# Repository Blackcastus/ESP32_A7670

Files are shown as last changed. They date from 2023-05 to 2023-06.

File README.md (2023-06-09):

Designer: Mr.Duc_Hien

## Lưu ý thiết kế Hardware.
- Khóa cửa thường hở 12V (dài x rộng x cao tối thiểu 49mm x 30mm x 20mm). -> check notOK
- Vị trí cổng USB trên tủ thay bằng khay sim. -> check OK
- Thêm led status cho simcom và PGS.
- Sử dụng các loại header cắp khác nhau để không bị cắm nhầm.
- Kiếm lại lò xo cho button.
- Thiết kế lại bus cắm LCD.
- Chú ý căn chỉnh LCD cho khớp với vỏ tủ.
- Kiếm lại IC UART - I2C chp bộ BMS.
- Thêm RS485 viết bằng software uart.

## Block diagram.
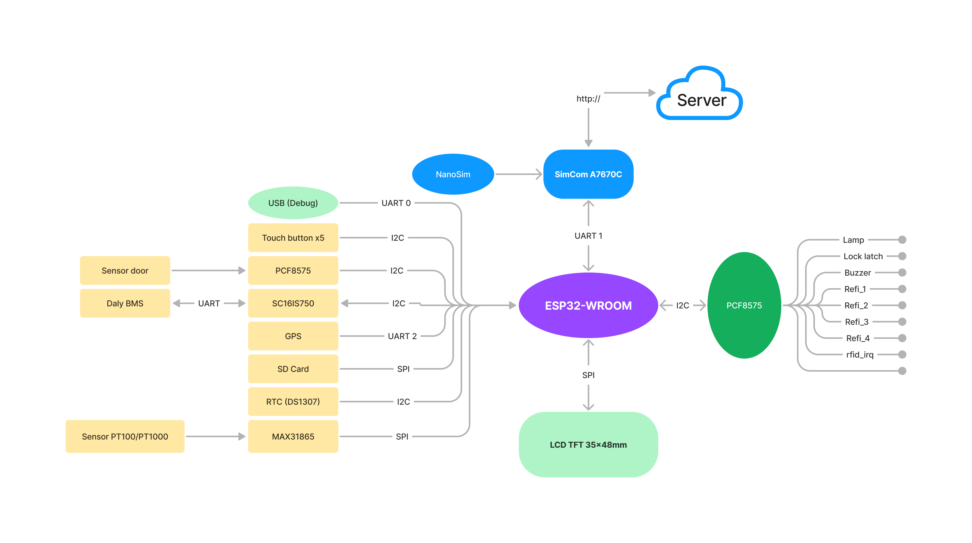
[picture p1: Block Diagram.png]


## Hardware MCU và Display

1. **Hardware board MCU.**

    **1.1. Thông số kỹ thuật board MCU:**

    * Nguồn input 12V được lấy từ bộ pin 12V hoặc qua adapter 12V.
    * MCU : ESP32-WROOM, debug qua USB.
    * Cảm biến: nhiệt độ PT100, cảm biến cửa.
    * Lấy vị trí GPS.
    * Kết nối module SIM 3G.
    * Đọc/lưu thời gian thực qua RTC.
    * Lưu dữ liệu vào thẻ nhớ.
    * Kết nối với màn hình LCD TFT 2Inch.
    * kết nối với bàn phím cảm ứng.
    * Có RS485 (sử dụng code software serial mới dùng được).
    * Điều khiển block lạnh.
    * Điều khiển khóa tủ.
    * Điều khiển đèn chiếu sáng trong tủ.
    * Điều khiểu chuông báo.
    * Đọc dữ liệu quản lý pin từ daly BMS.
    
    **1.2. Hình ảnh bộ quản lý pin BMS**

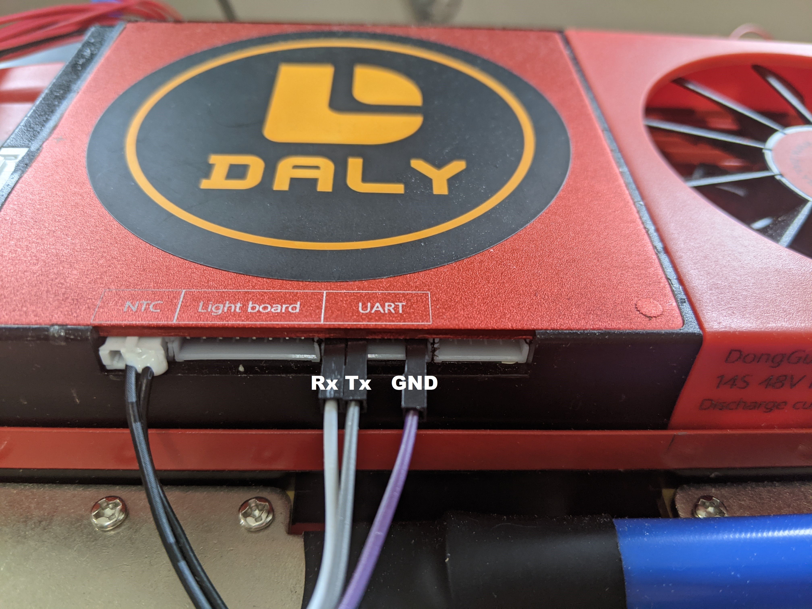
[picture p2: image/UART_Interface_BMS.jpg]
    

    **1.3. Hình ảnh board**

    Top layer

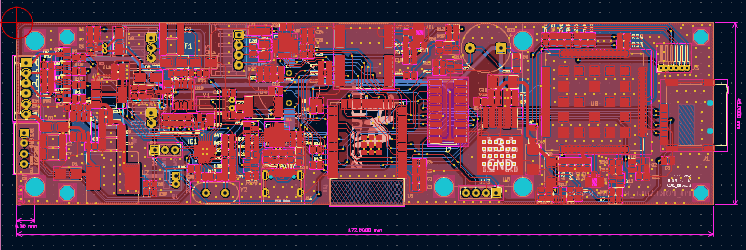
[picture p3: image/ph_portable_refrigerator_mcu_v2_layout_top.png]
    
    
    Bottom layer

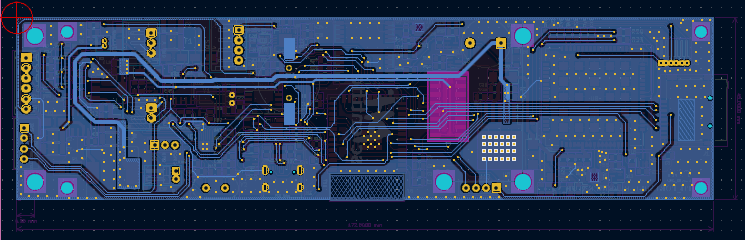
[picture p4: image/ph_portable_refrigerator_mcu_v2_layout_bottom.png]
    

    Top 3D

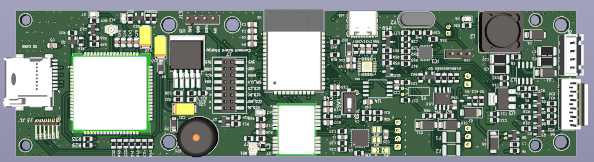
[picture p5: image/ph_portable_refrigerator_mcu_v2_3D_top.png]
    

    Bottom 3D

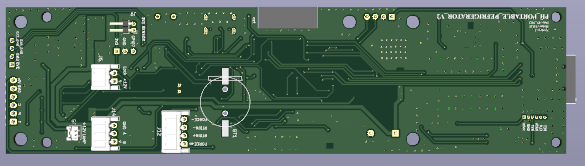
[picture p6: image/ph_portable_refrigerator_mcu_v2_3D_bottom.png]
    

2. Hardware board display.

    **2.1. Thông số kỹ thuật board display**
    * Điện áp: 3V3.
    * Giao tiếp với LCD qua giao thức SPI.
    * Giao tiếp với bàn phím cảm ứng qua giao thức I2C.
    * Có chuông báo.

    **2.2. Hình ảnh board**

    Top layer

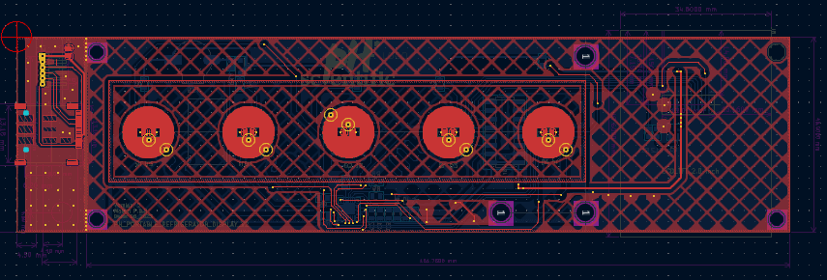
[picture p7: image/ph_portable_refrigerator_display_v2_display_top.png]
    
    
    Bottom layer
    
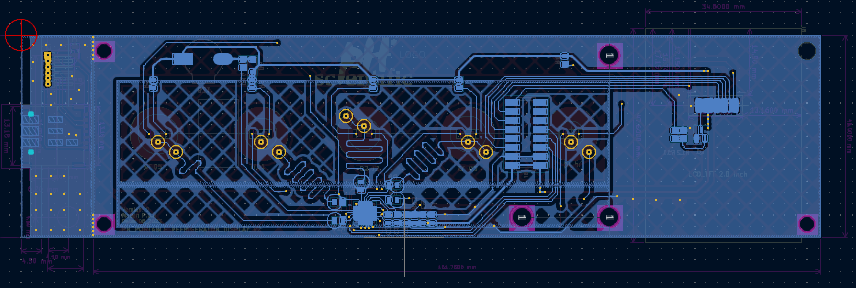
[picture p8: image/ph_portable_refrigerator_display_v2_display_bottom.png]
    

    Top 3D

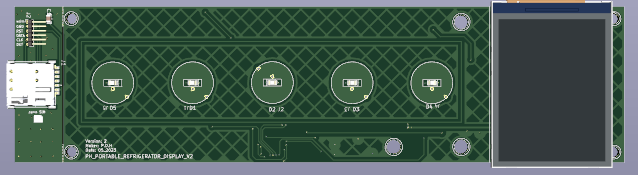
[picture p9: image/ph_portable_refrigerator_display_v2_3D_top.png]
    

    Bottom 3D

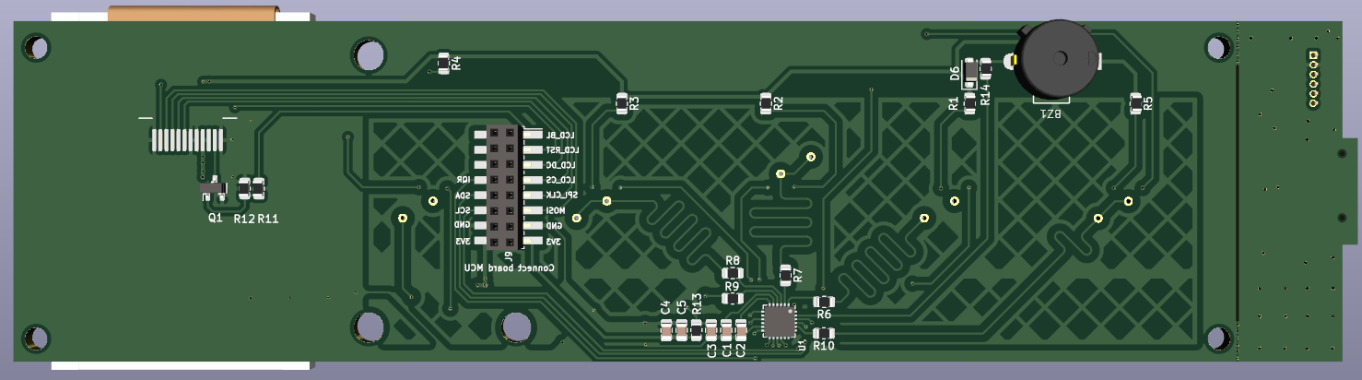
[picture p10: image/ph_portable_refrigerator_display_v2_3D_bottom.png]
    

    Board sau khi hàn 

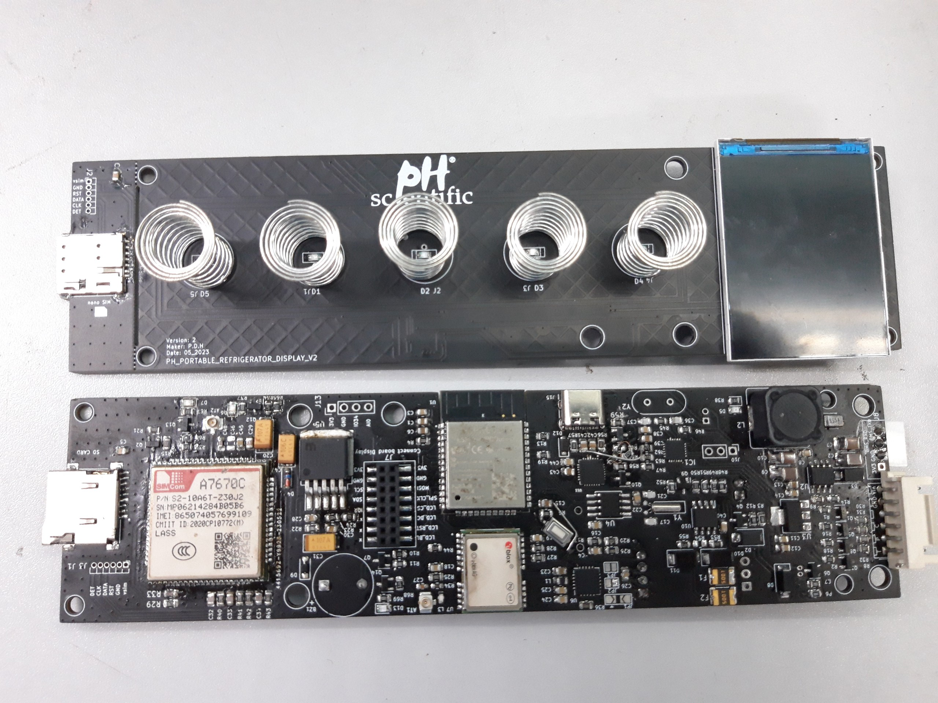
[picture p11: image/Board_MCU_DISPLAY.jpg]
    

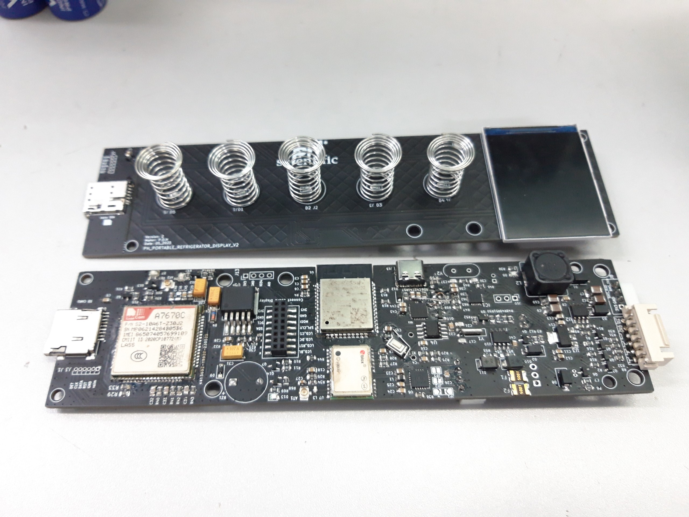
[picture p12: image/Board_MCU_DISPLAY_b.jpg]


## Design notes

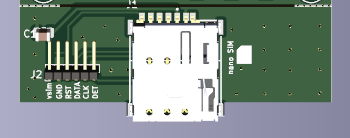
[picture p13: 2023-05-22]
Hardware/image/module_nanoSIM.png

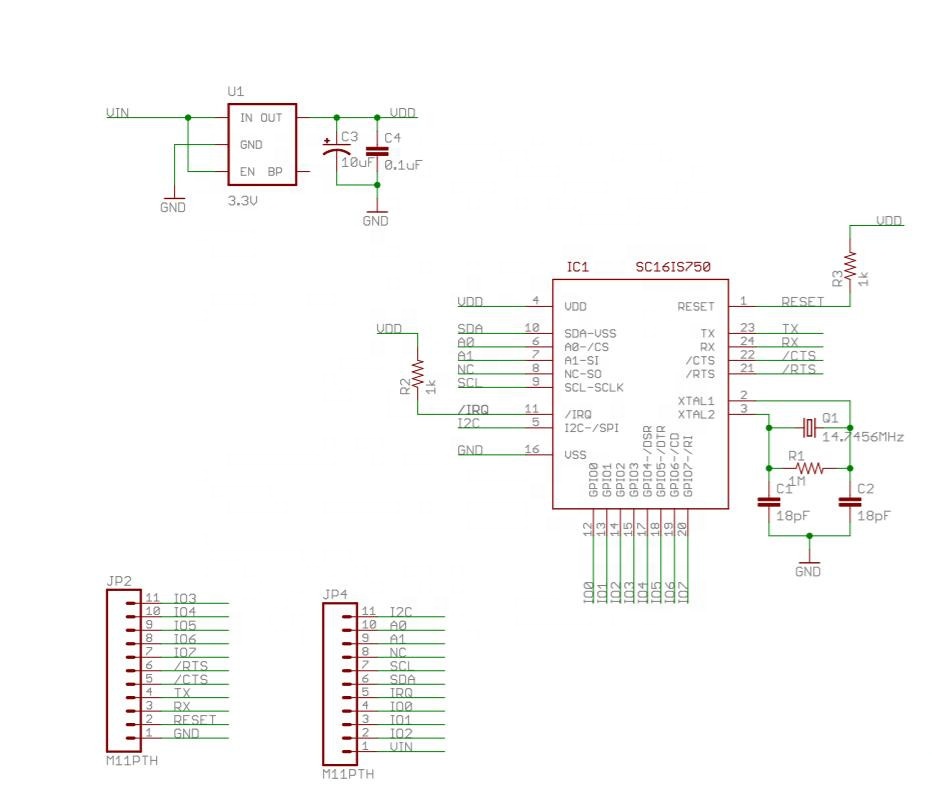
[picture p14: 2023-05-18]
Hardware/power_v2/Uart to I2C.jpeg

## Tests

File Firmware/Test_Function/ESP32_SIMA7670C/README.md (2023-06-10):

#ESP32 - SIMCOM A7670C

#Connect
    *Communication: UART.
    *Baut rate: 115200.

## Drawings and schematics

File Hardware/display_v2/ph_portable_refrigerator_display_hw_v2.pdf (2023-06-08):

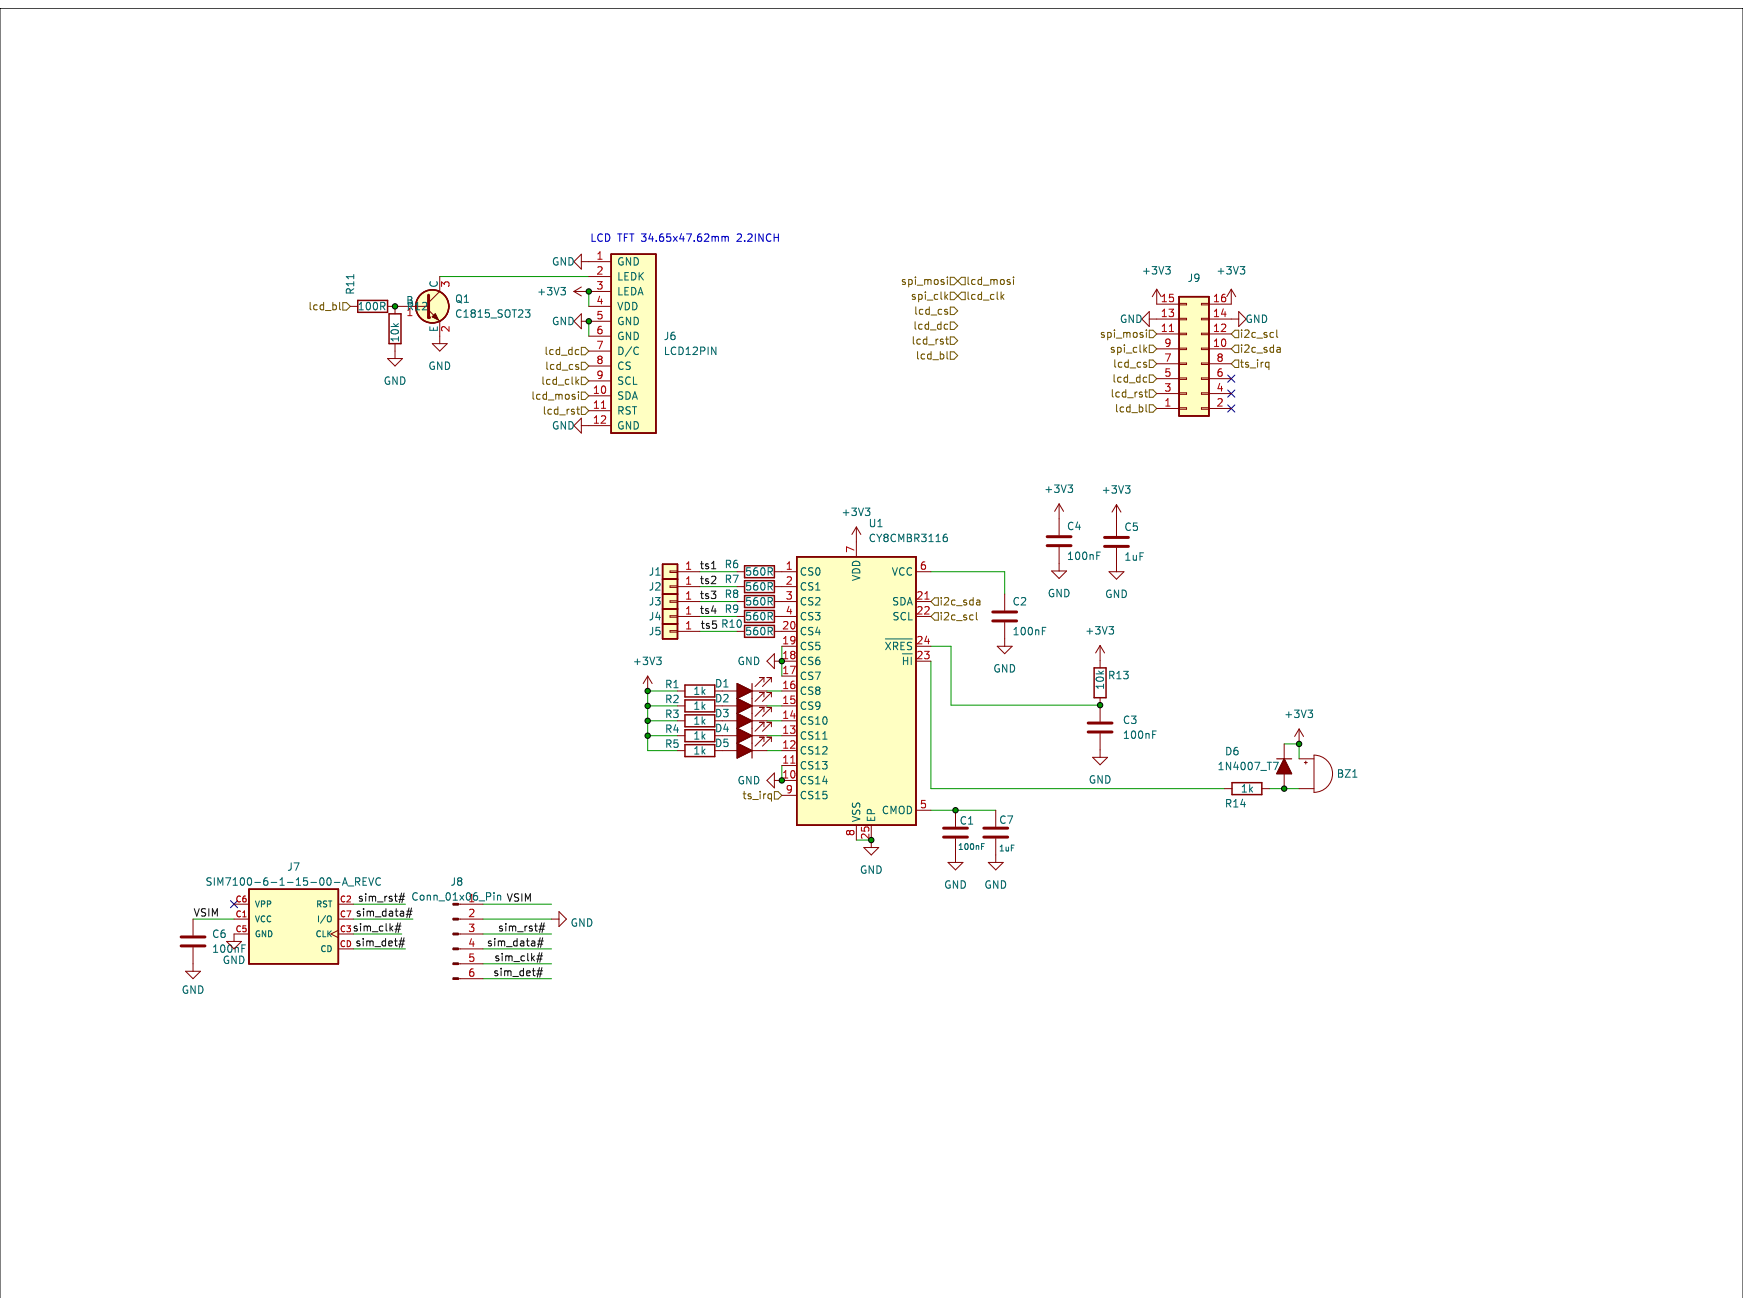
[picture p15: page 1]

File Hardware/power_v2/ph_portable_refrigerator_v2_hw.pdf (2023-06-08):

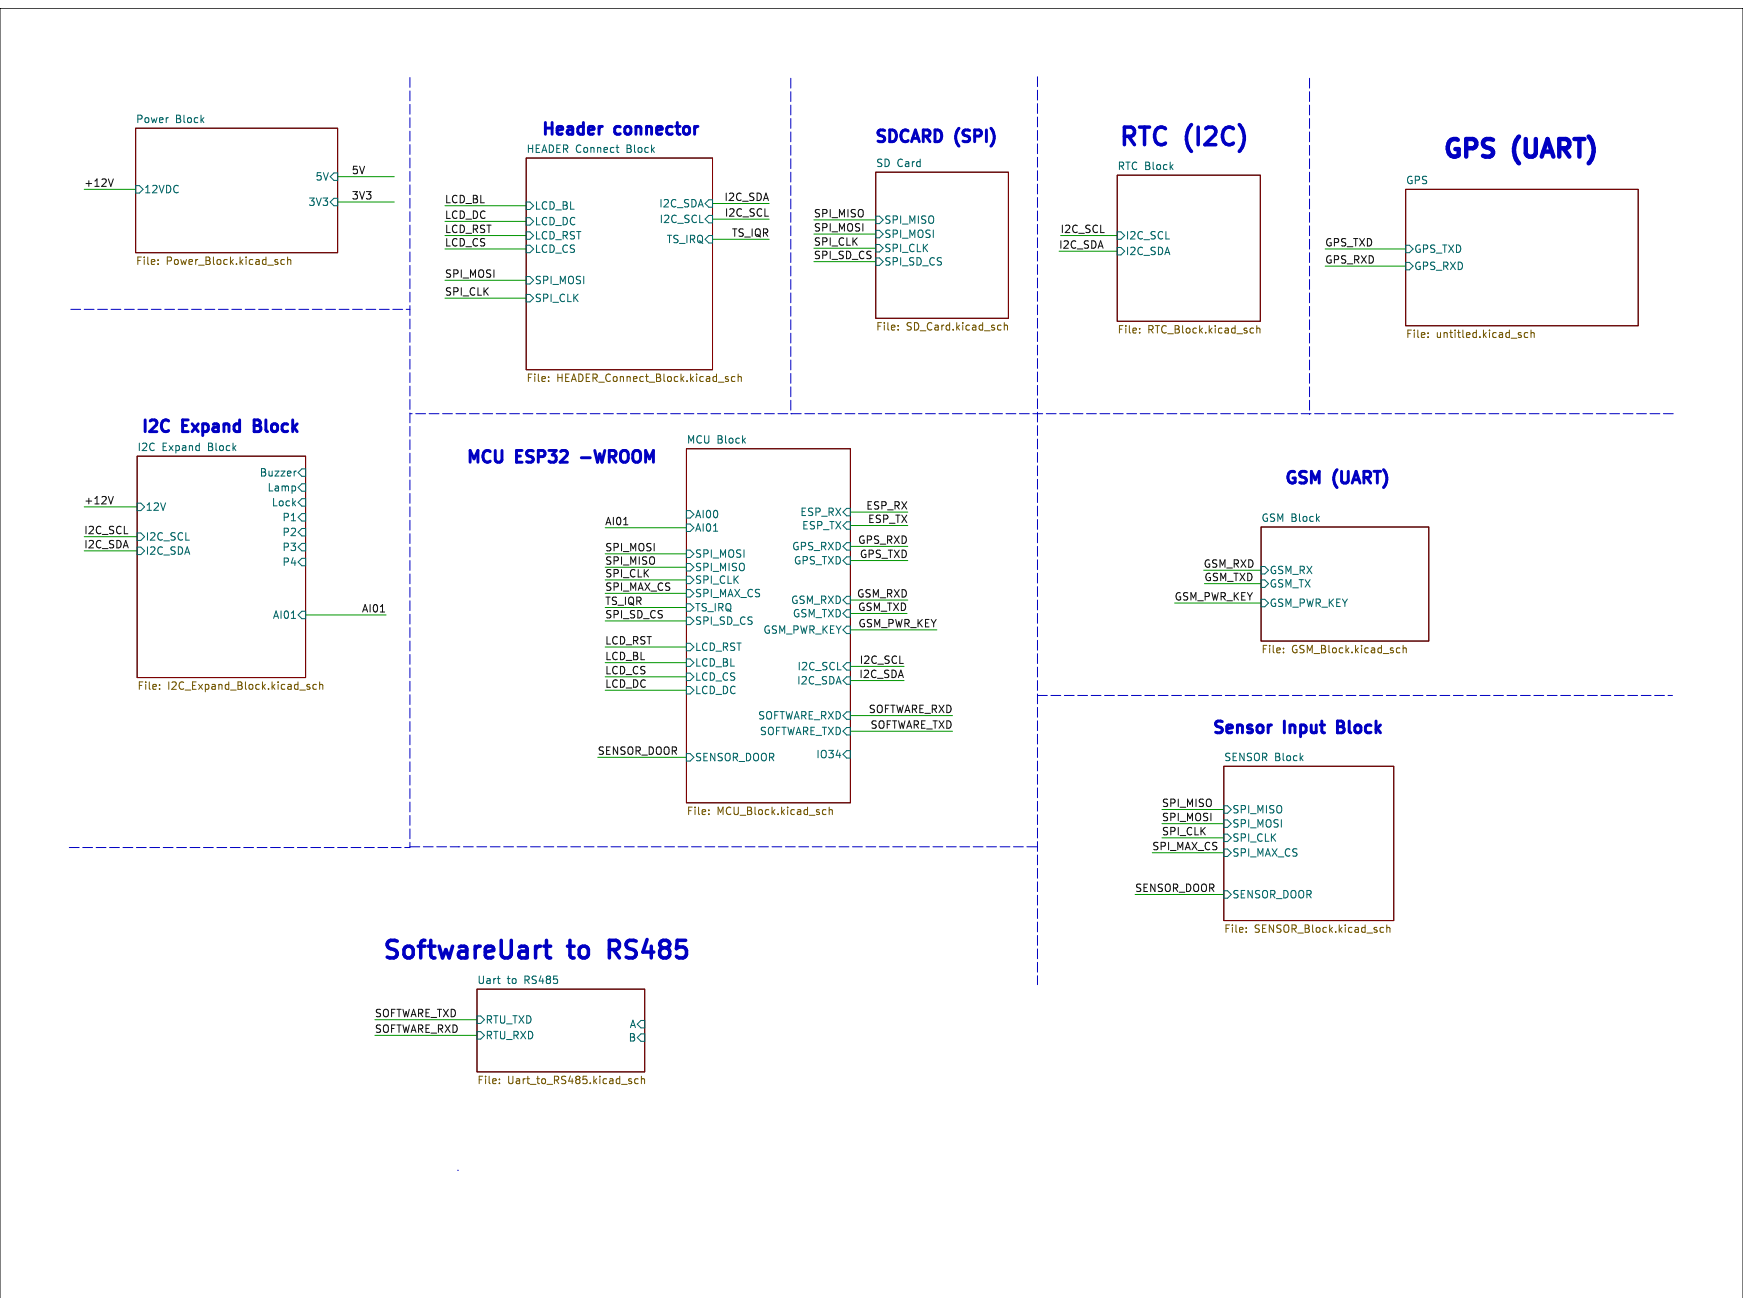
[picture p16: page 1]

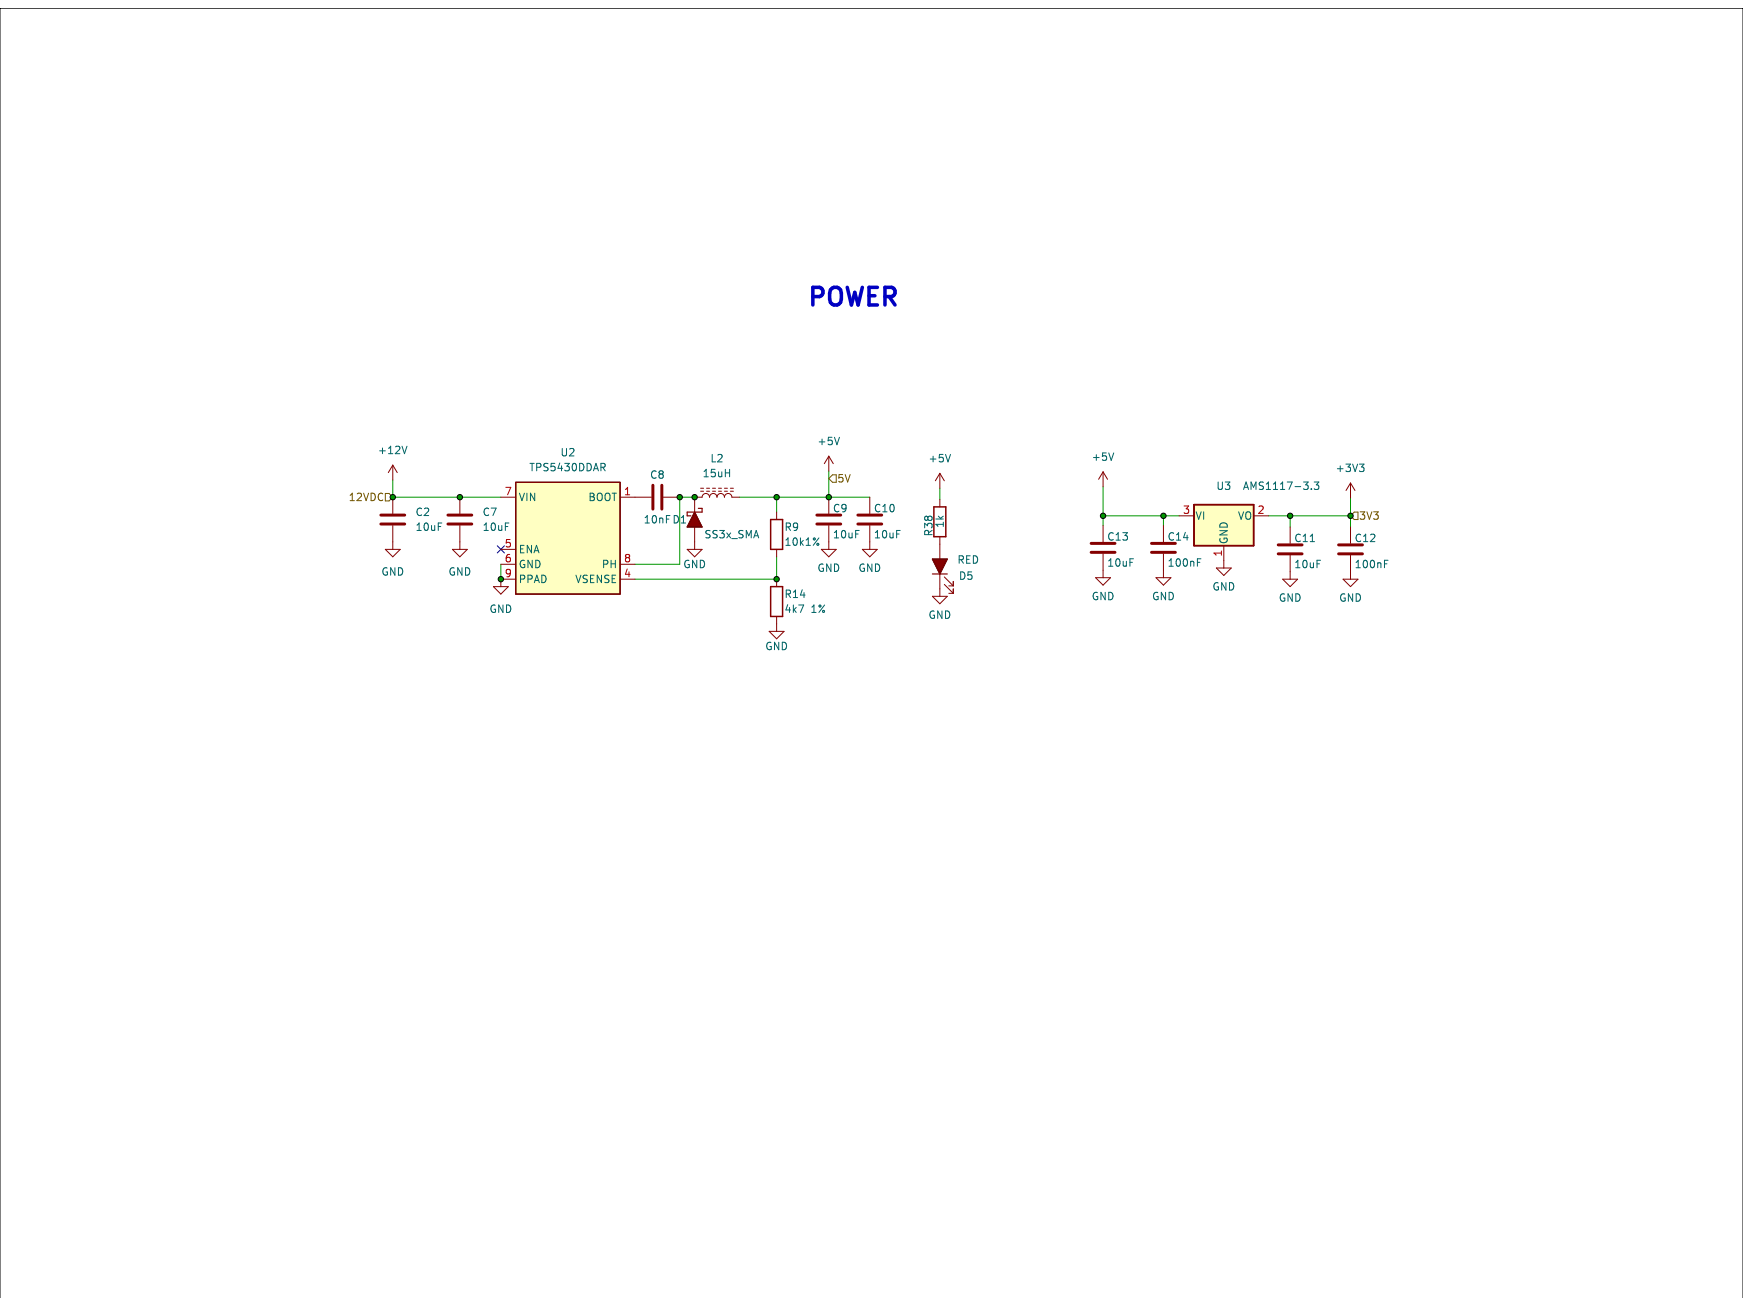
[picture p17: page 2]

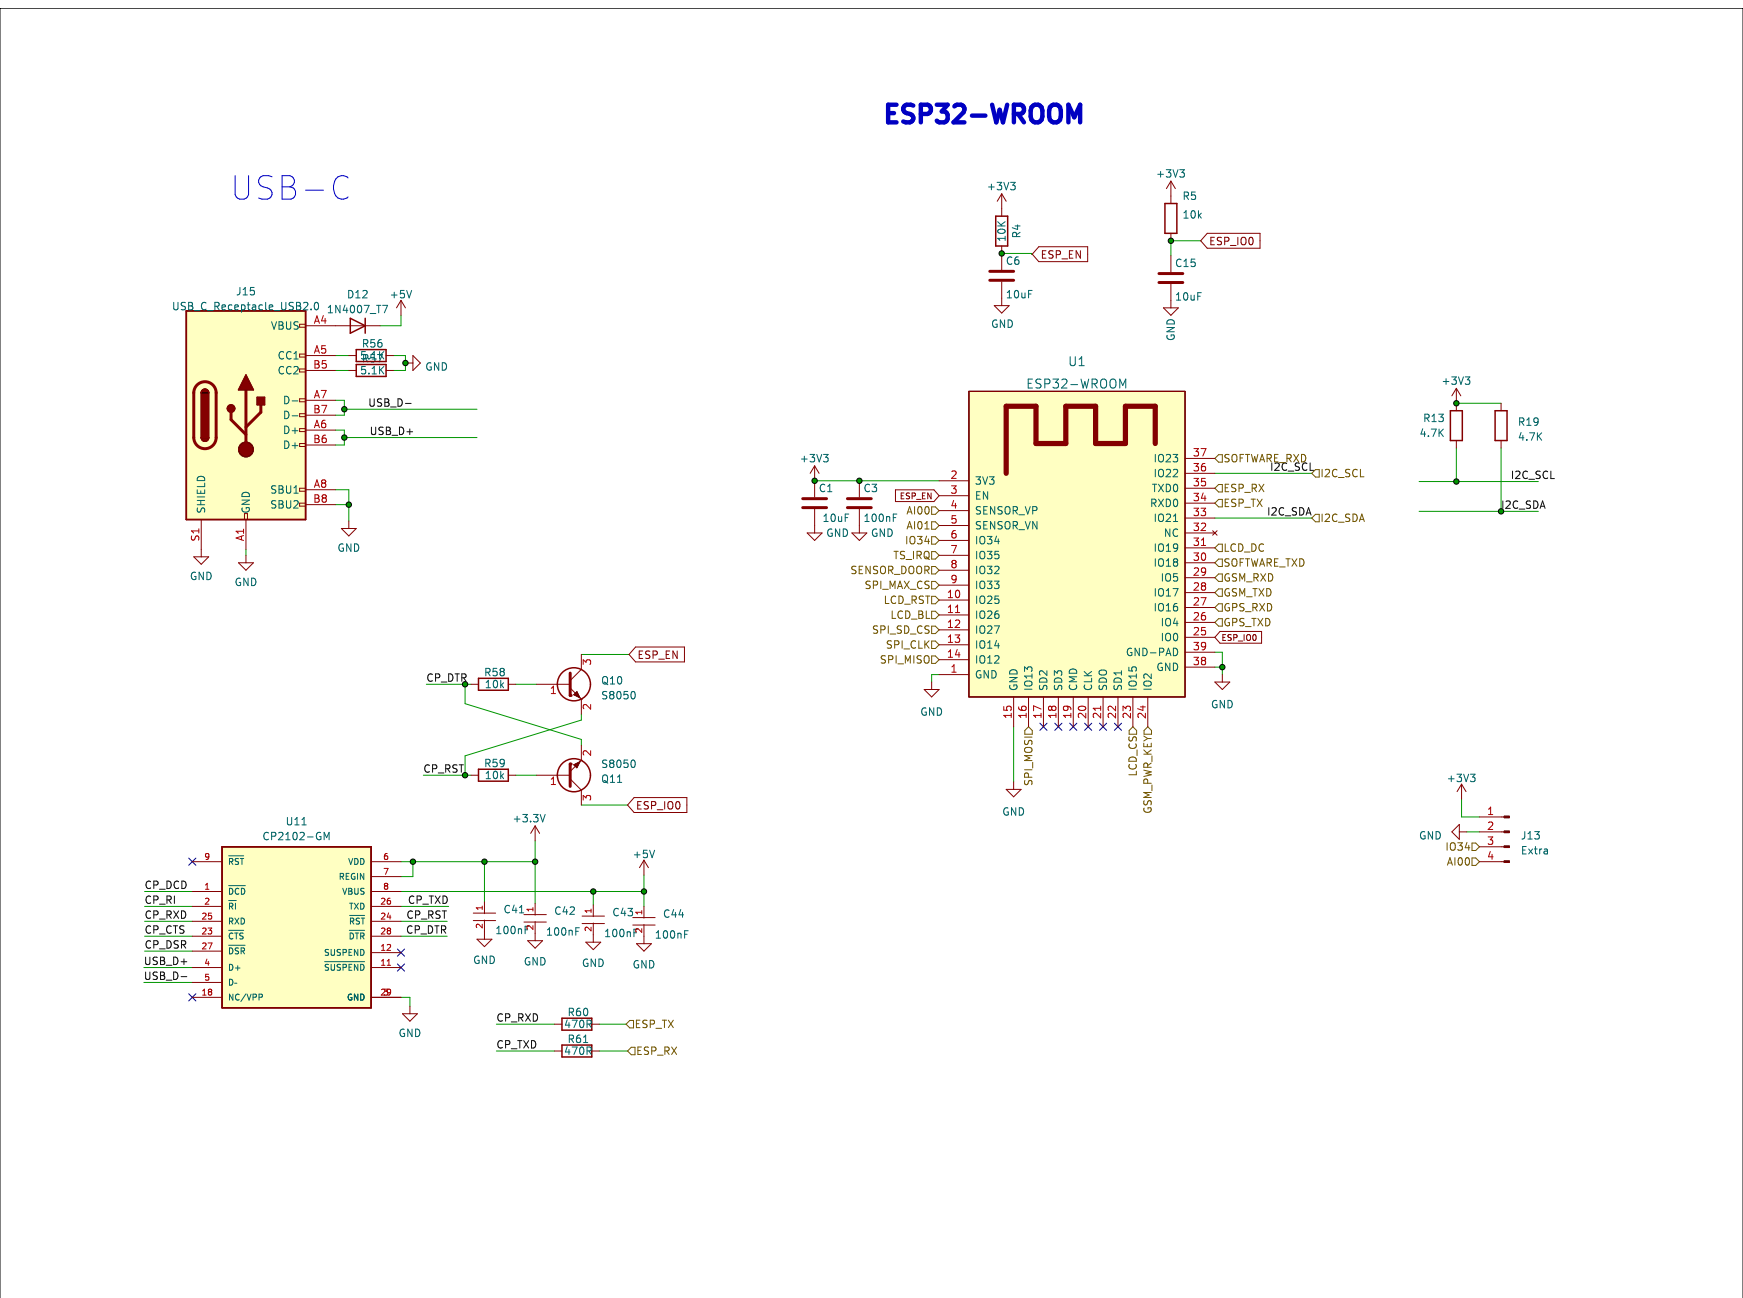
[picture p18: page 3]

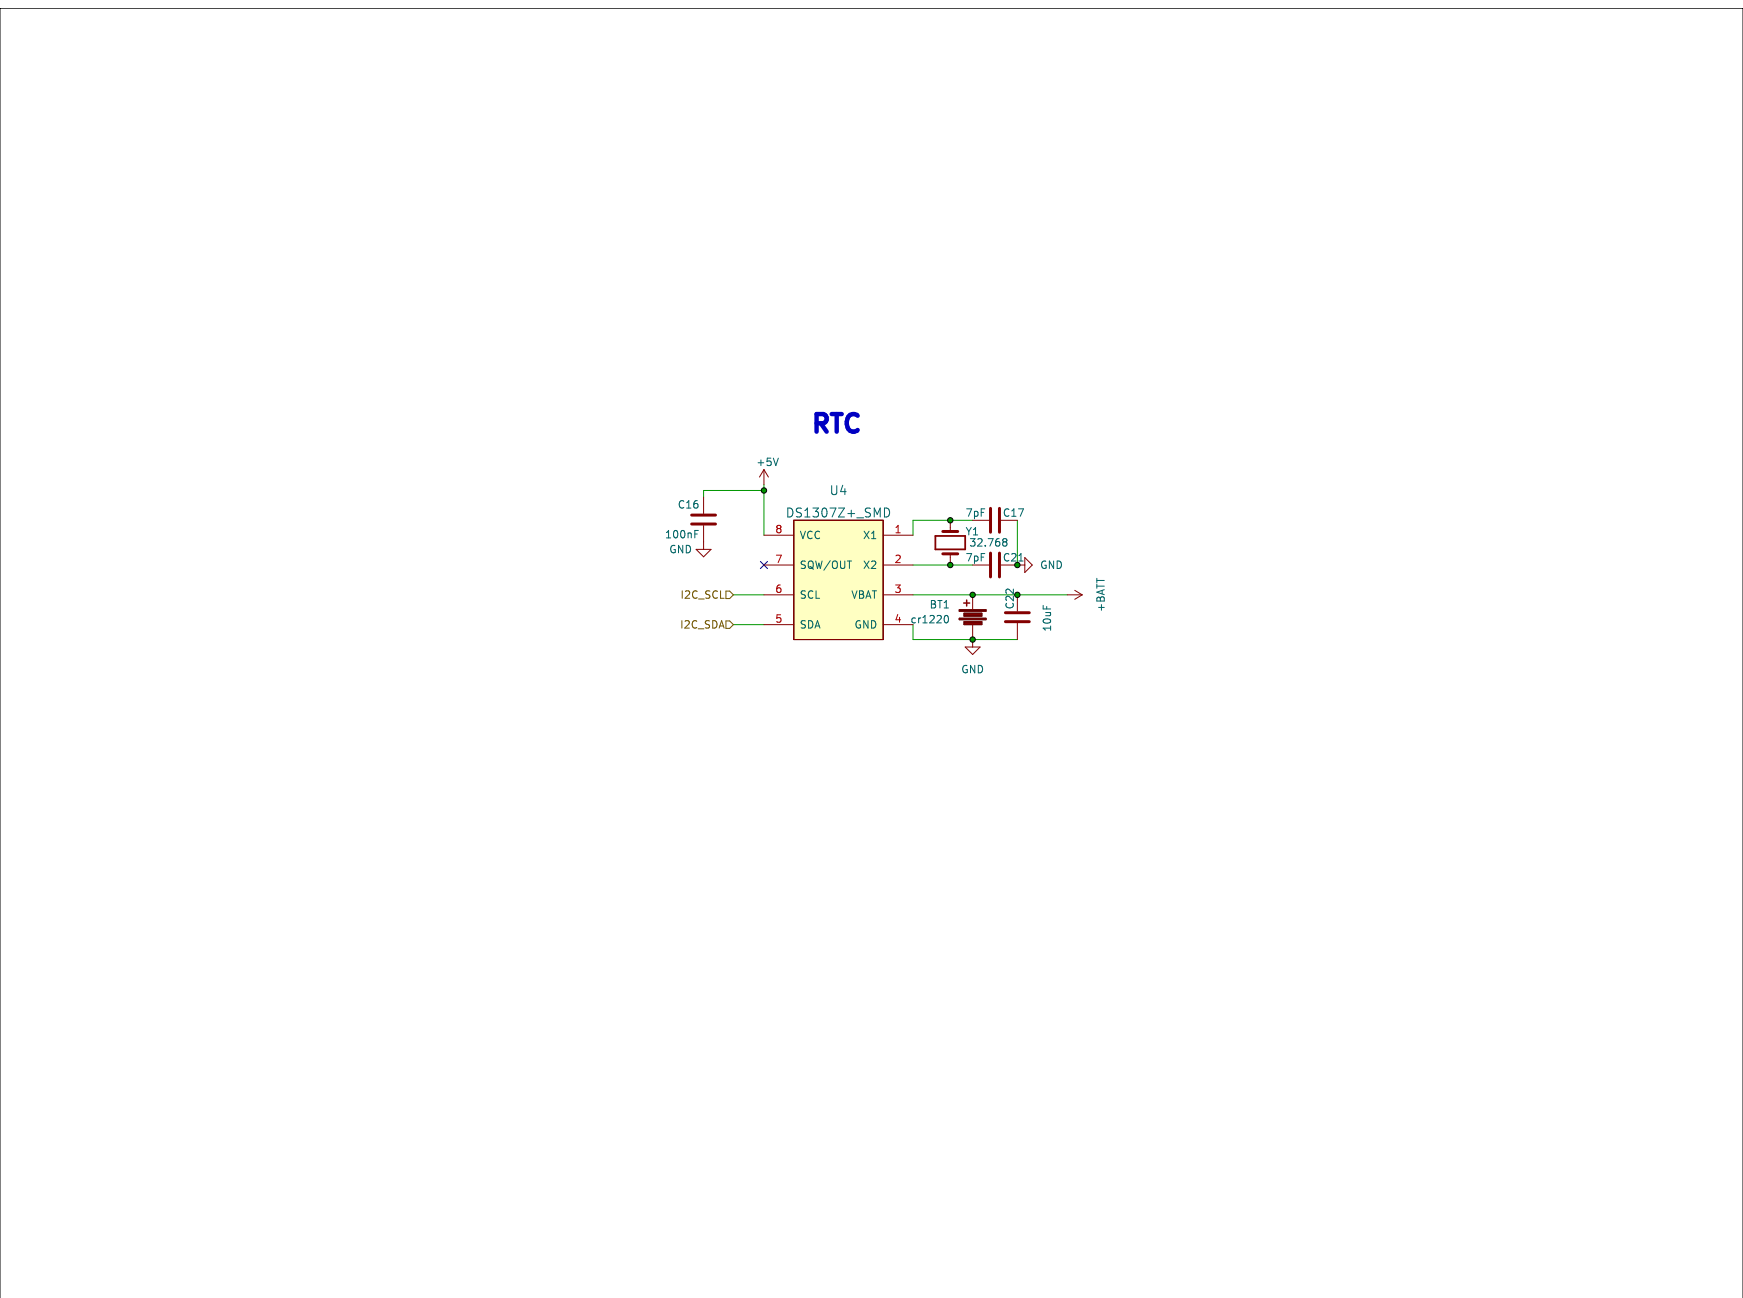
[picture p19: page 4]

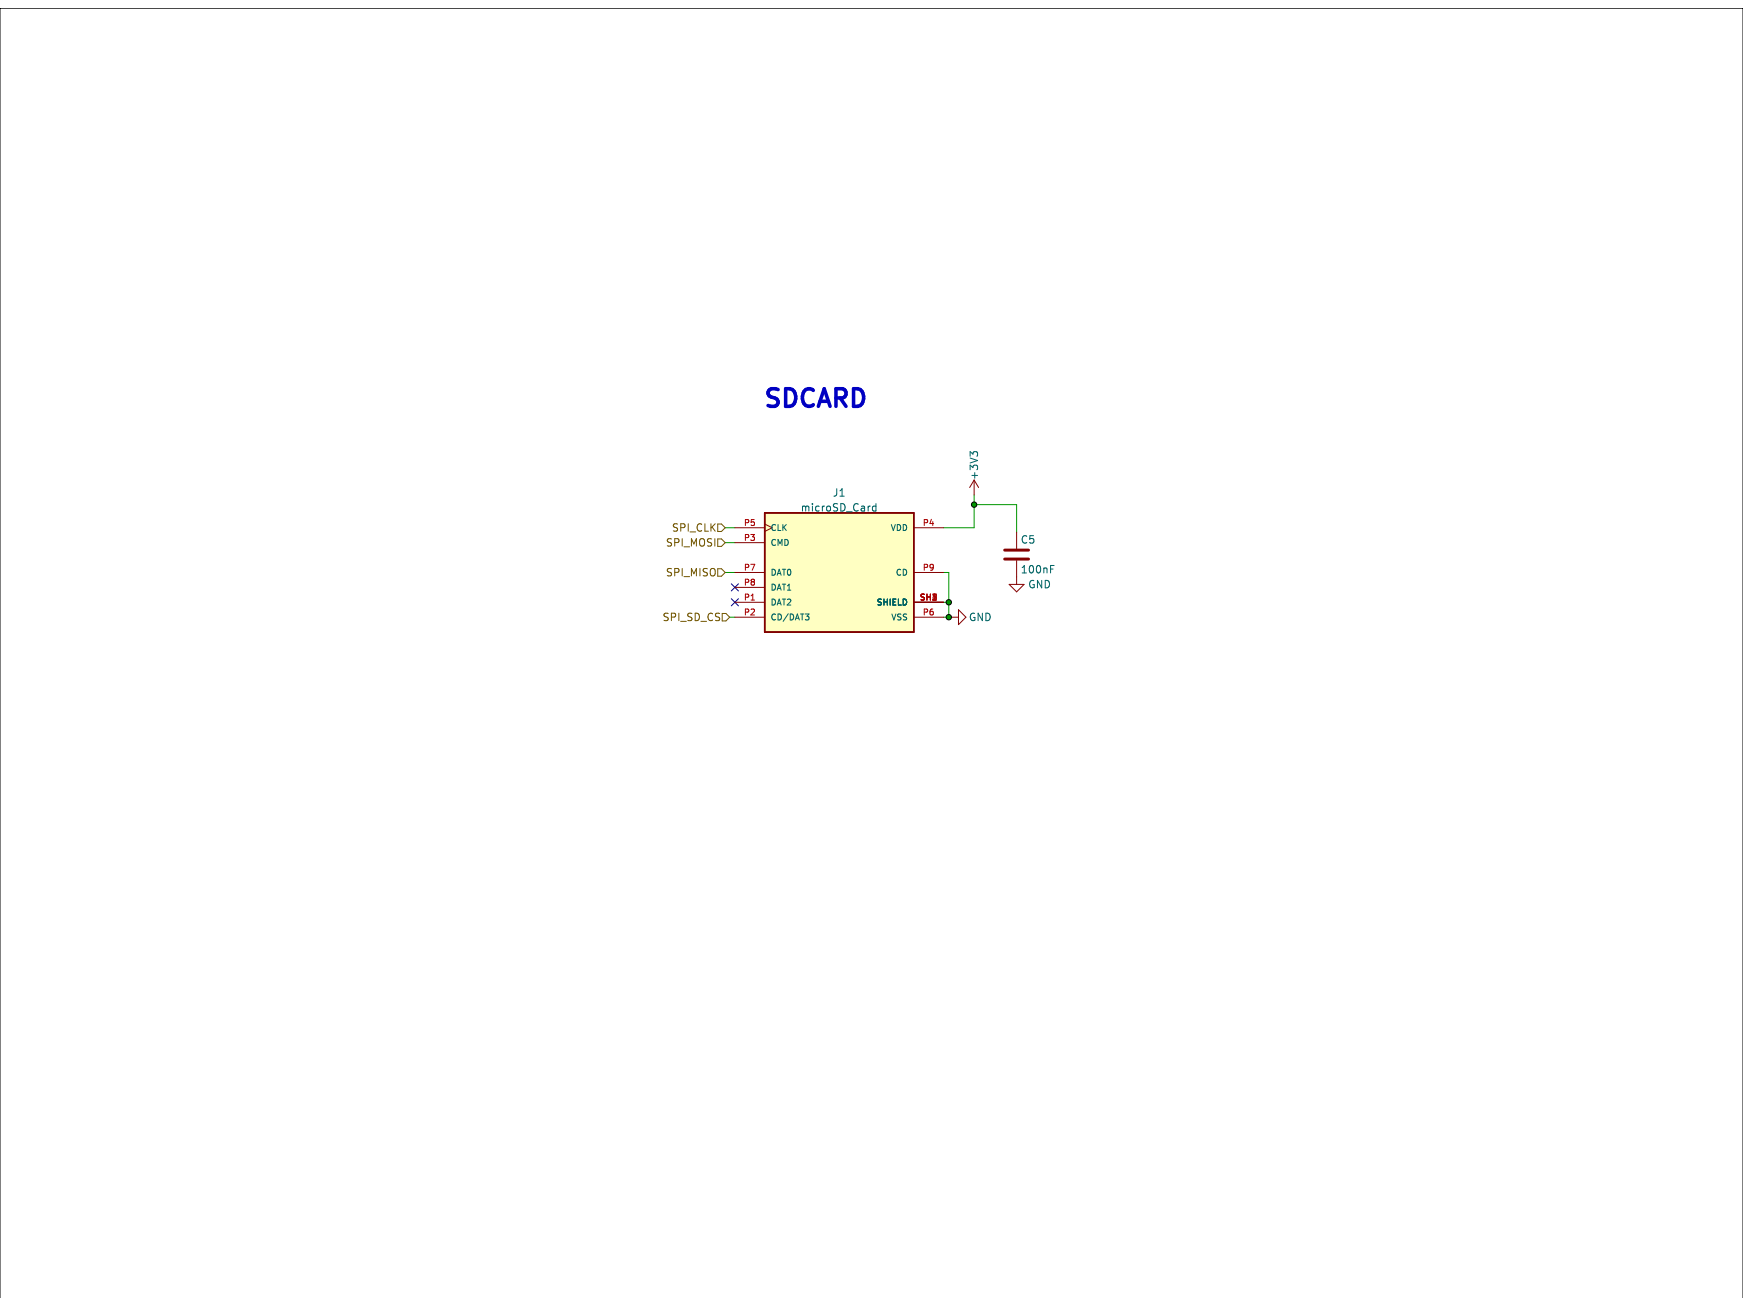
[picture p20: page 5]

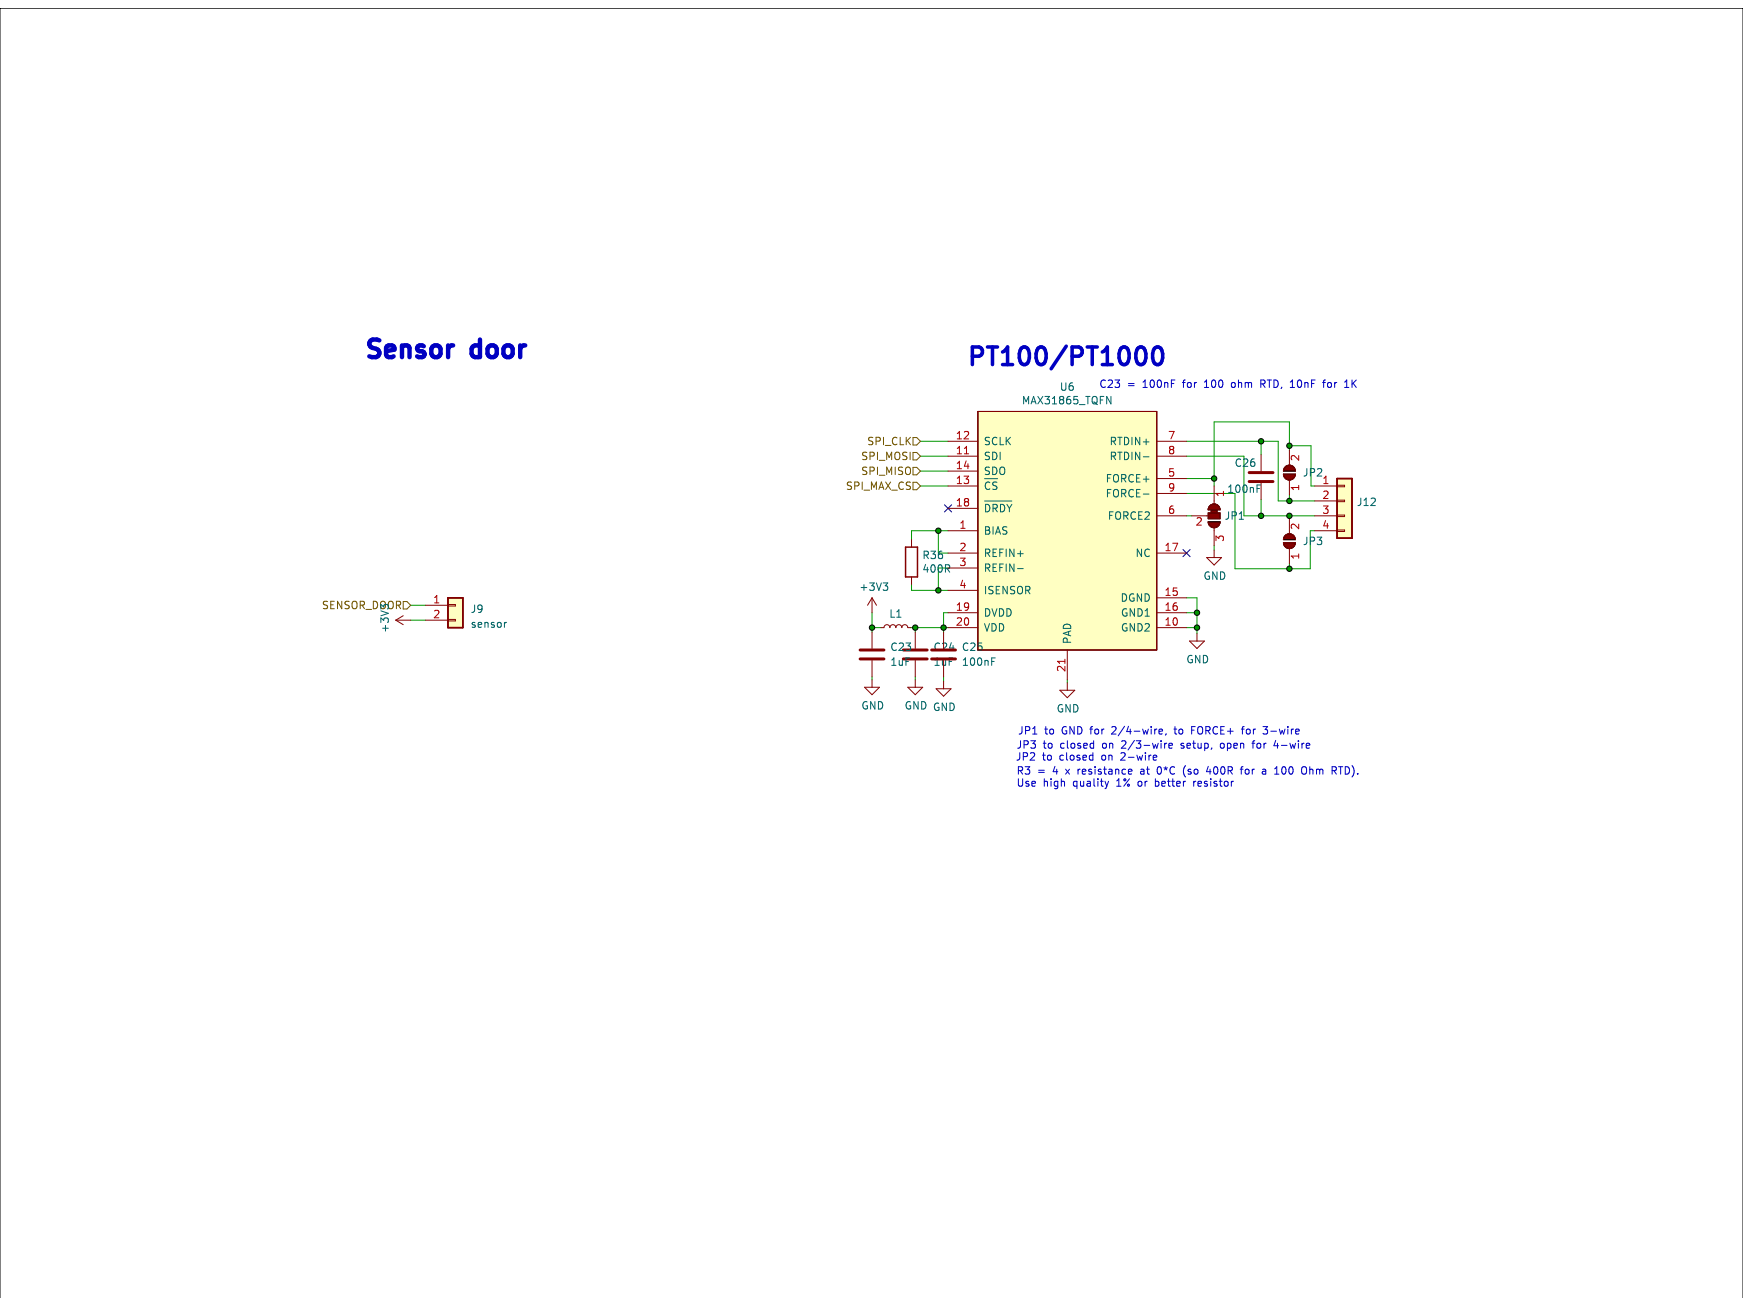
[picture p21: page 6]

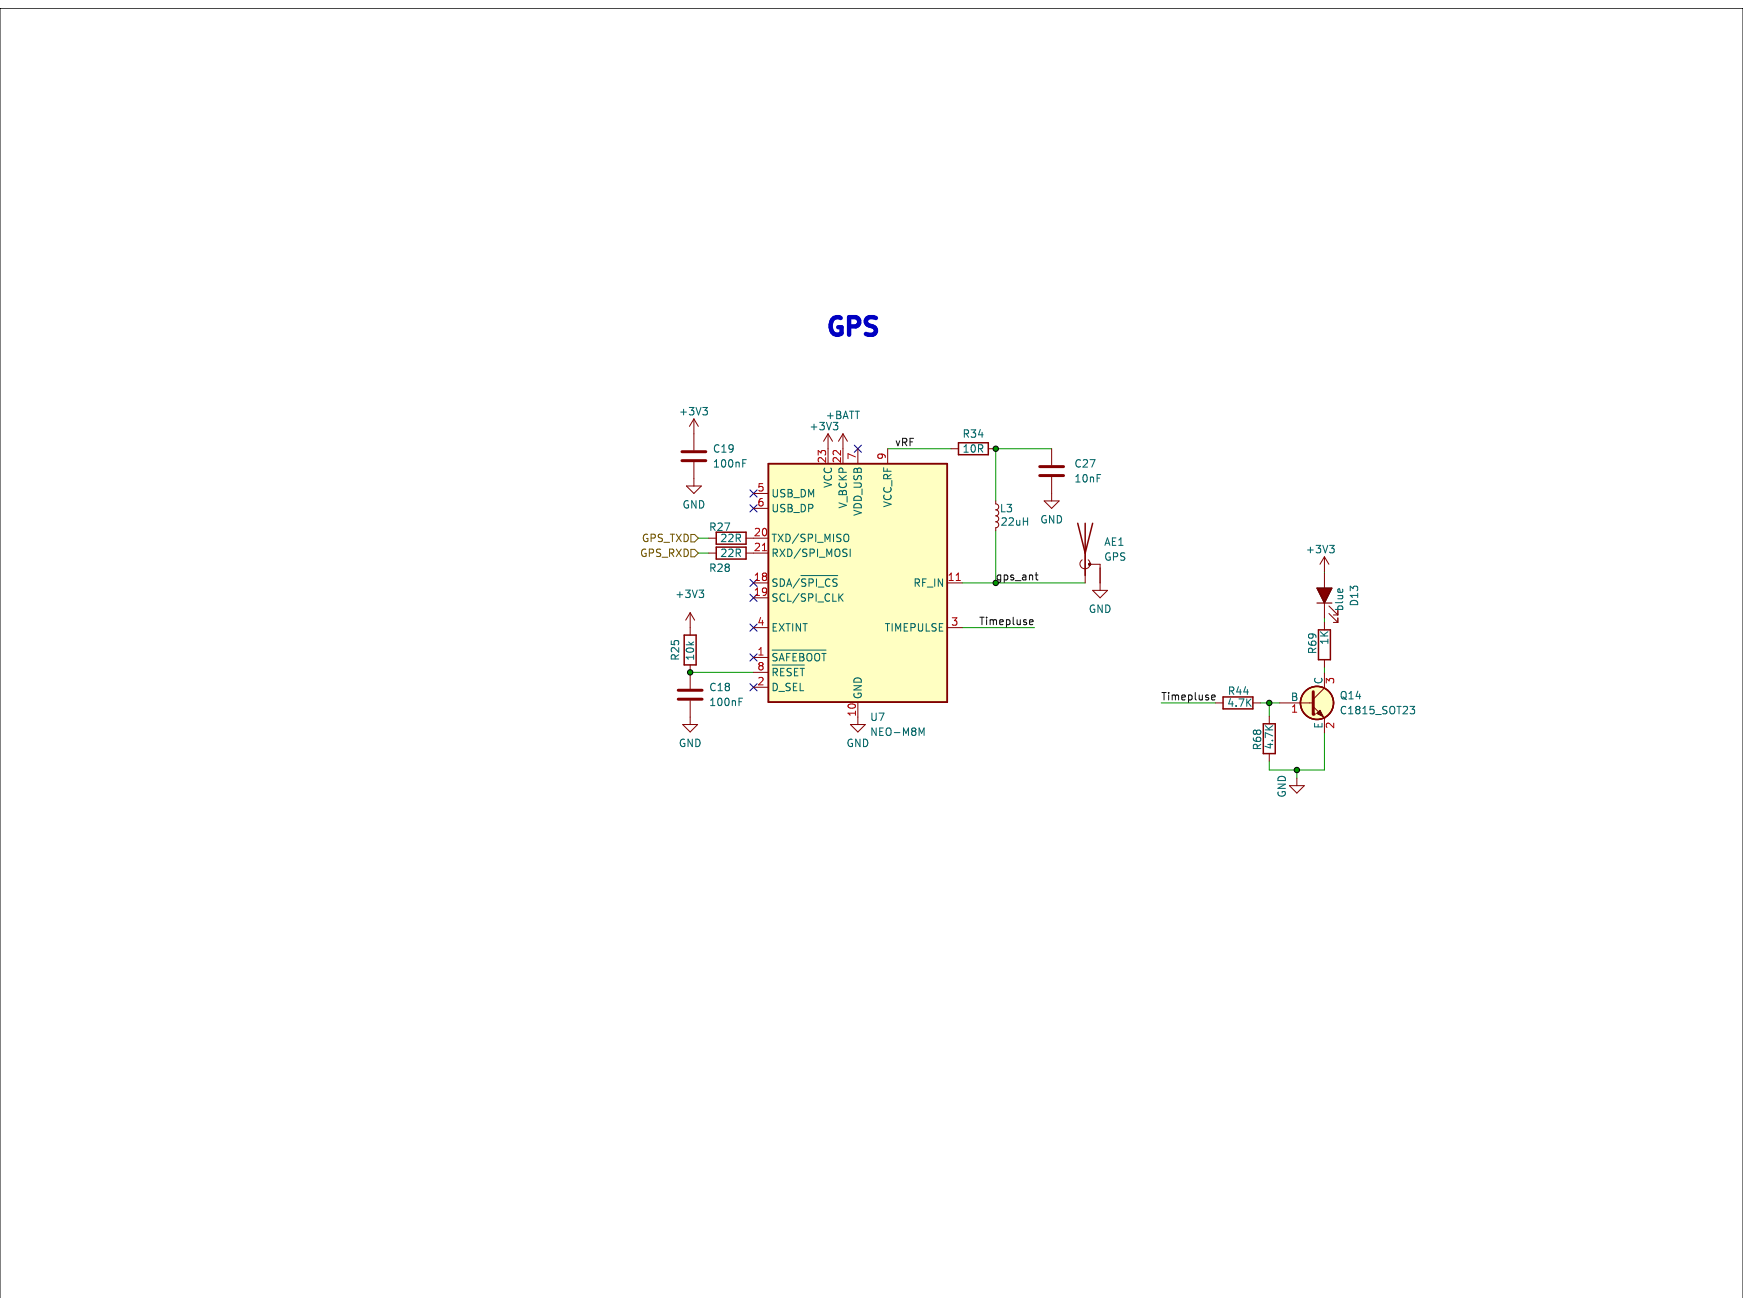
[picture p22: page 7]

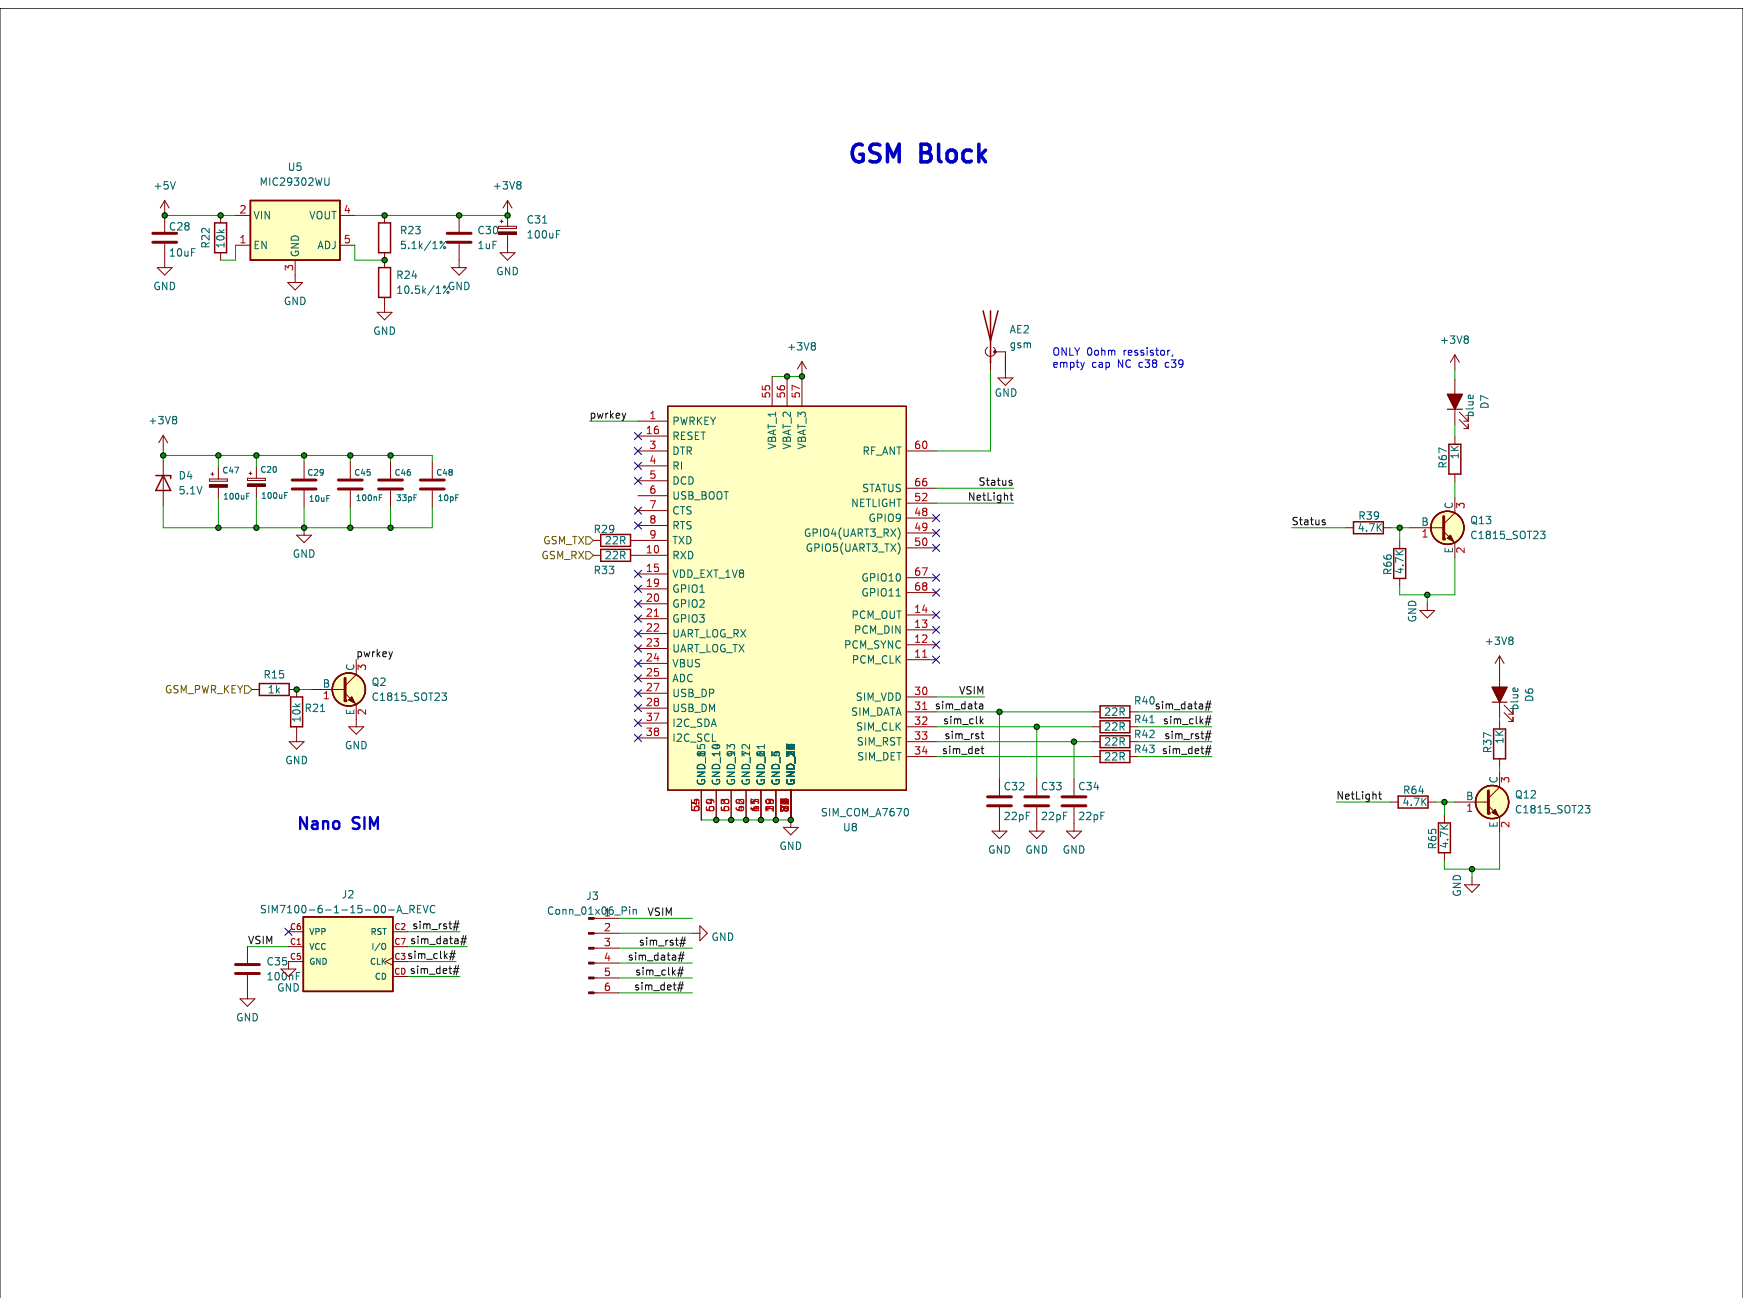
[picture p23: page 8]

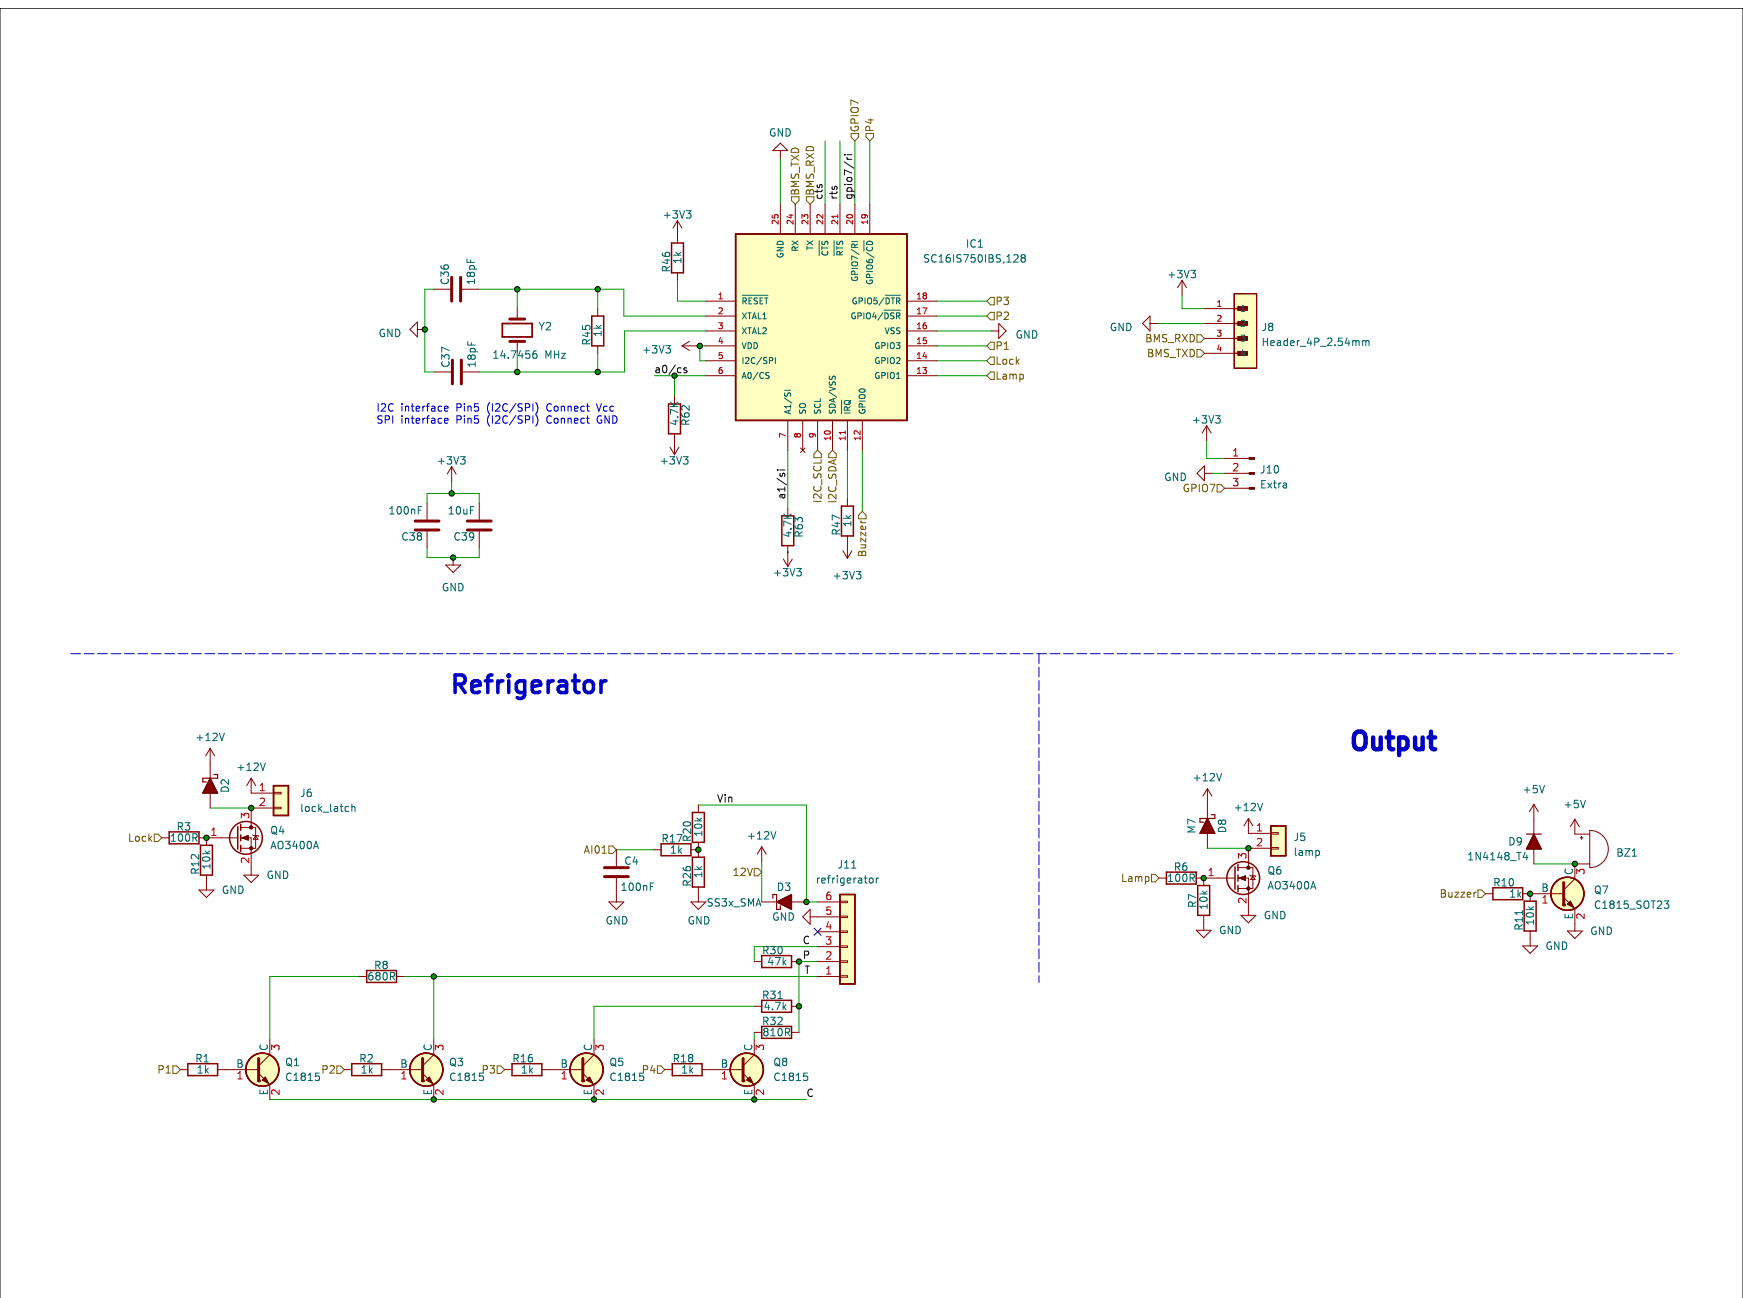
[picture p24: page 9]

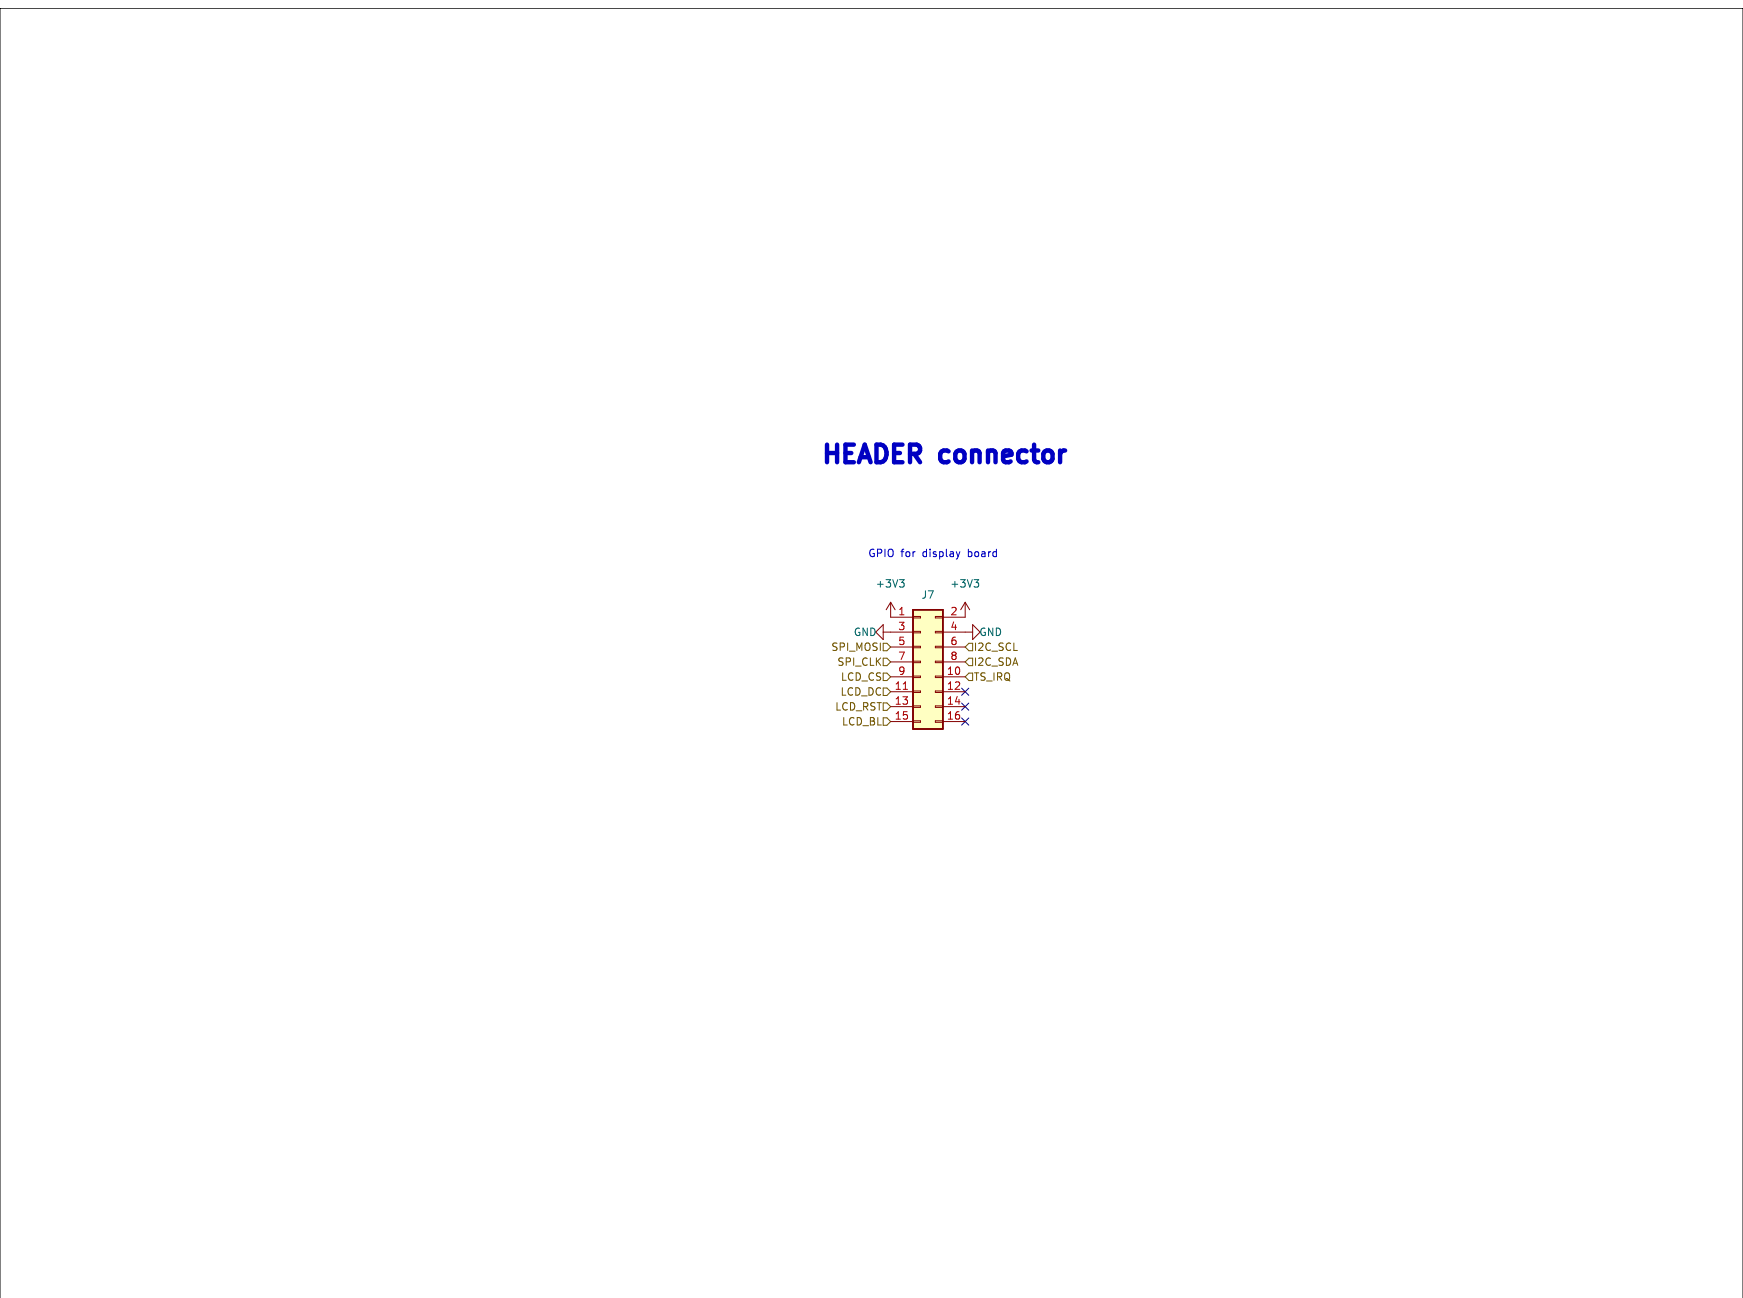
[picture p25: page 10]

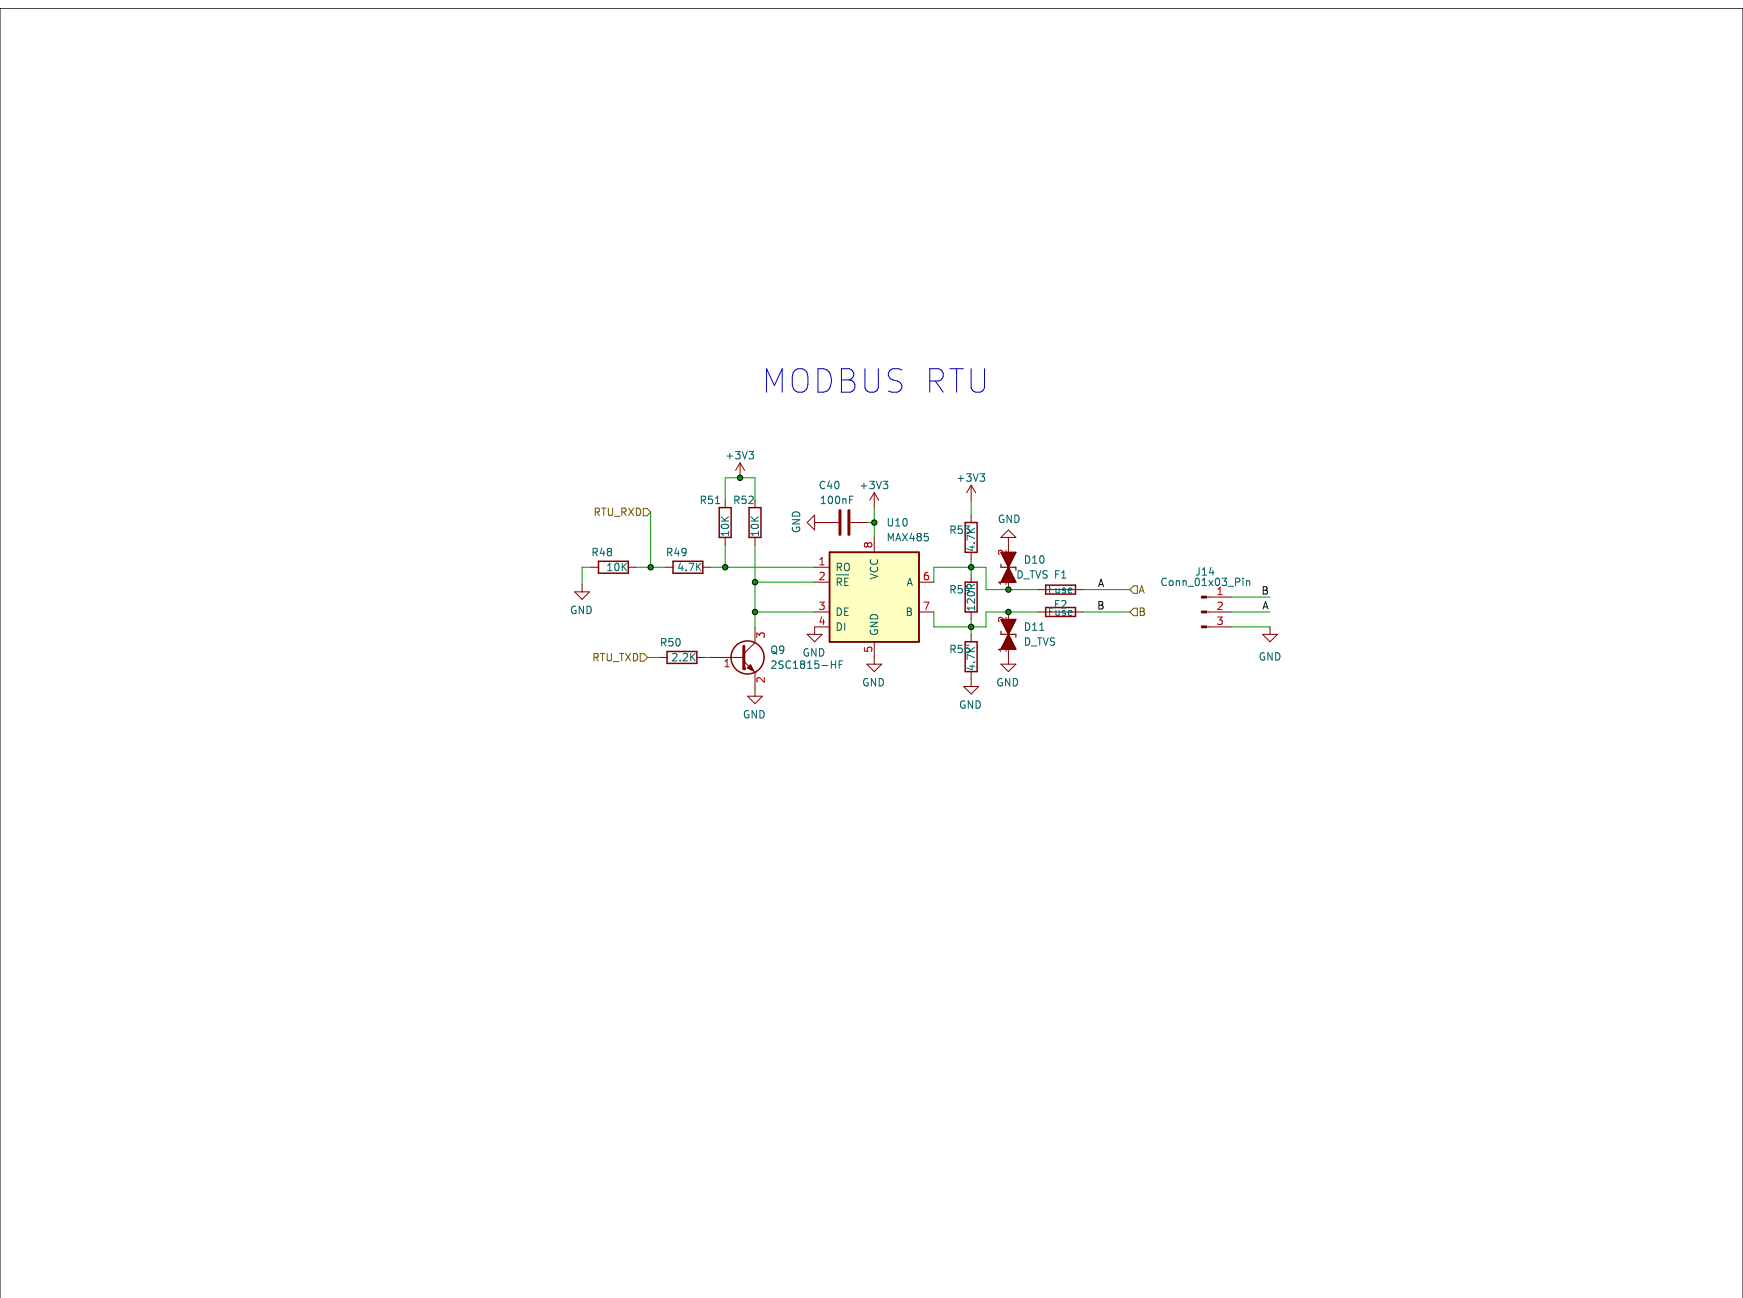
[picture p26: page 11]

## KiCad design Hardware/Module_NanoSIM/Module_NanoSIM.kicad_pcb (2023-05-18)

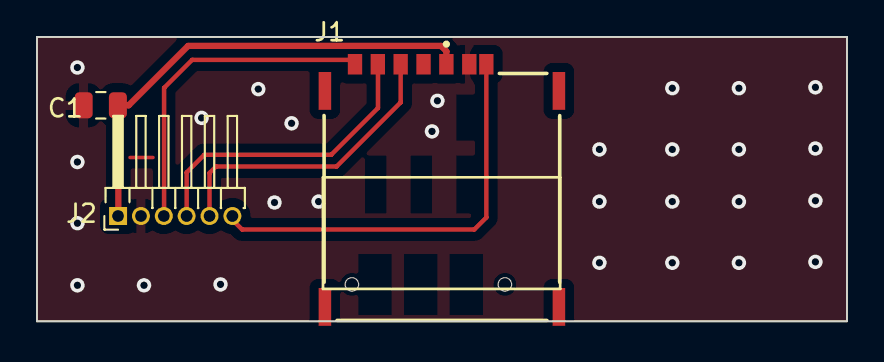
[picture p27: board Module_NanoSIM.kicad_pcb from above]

Board: 2 copper layers, 45.0 x 15.8 mm, 3 parts (0 on the bottom side), 6 nets.

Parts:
C1: 100nF; C_0805_2012Metric
J1: SIM7100-6-1-15-00-A_REVC; microSIM_Card
J2: Conn_01x06_Pin; PinHeader_1x06_P1.27mm_Horizontal

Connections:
/VSIM: C1.1, J1.C1 (VCC), J2.1
/sim_clk#: J1.C3 (CLK), J2.3
/sim_data#: J1.C7 (I/O), J2.4
/sim_det#: J1.CD, J2.6
/sim_rst#: J1.C2 (RST), J2.5
GND: C1.2, J1.C5 (GND), J2.2

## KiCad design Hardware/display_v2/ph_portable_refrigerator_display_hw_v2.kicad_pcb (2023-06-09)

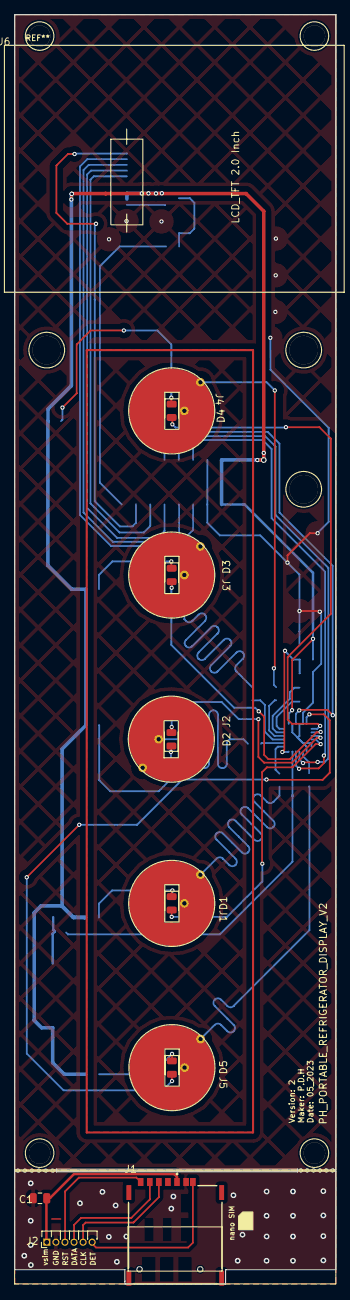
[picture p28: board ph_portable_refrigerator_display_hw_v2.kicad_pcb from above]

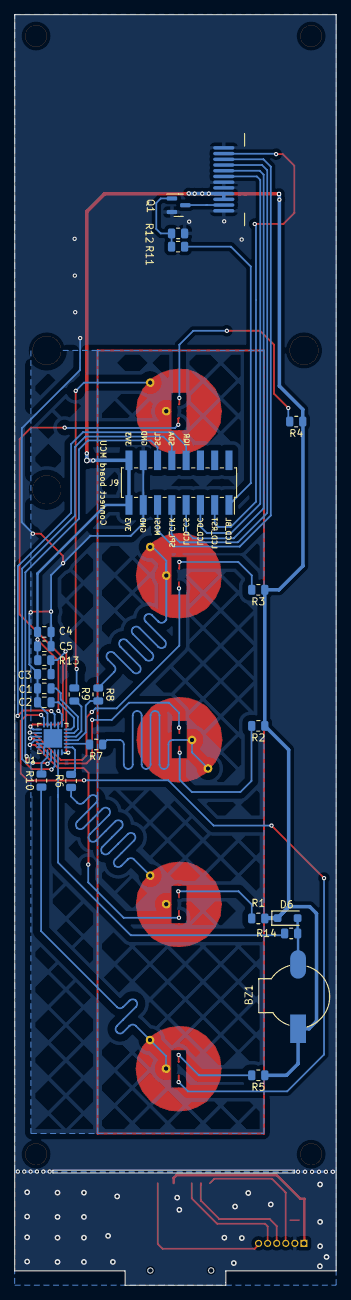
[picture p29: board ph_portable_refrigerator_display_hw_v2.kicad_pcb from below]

Board: 2 copper layers, 45.0 x 177.8 mm, 38 parts (24 on the bottom side), 38 nets.

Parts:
BZ1: Buzzer-Device; Buzzer_SMD_9633
C1, C2, C3, C4: 100nF; C_0805_2012Metric
C1#2: 2.2nF; C_0805_2012Metric
C5: 10uF; C_0805_2012Metric
D1, D2, D3, D4, D5: LED0805; LED_0805_2012Metric
D6: 1N4007_T7; D_SOD-123F
J1: SIM7100-6-1-15-00-A_REVC; microSIM_Card
J1#2, J2#2, J3, J4, J5: Conn_01x01; Button_Touch_Circle
J2: Conn_01x06_Pin; PinHeader_1x06_P1.27mm_Horizontal
J6: LCD12PIN; LCD_TFT_34.6x47.6mm_2INCH
J9: Conn_02x08_Odd_Even; PinSocket_2x08_P2.00mm_Vertical_SMD
Q1: C1815_SOT23; SOT-23
R1, R2, R3, R4, R5, R14: 1k; R_0805_2012Metric
R6, R7, R8, R9, R10: 560R; R_0805_2012Metric
R11: 100R; R_0805_2012Metric
R12, R13: 10k; R_0805_2012Metric
U1: CY8CMBR3116; QFN-24-1EP_4x4mm_P0.5mm_EP2.6x2.6mm

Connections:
+3V3: BZ1.1 (-), C4.1, C5.1, D6.1 (K), J6.3 (LEDA), J6.4 (VDD), J9.15, J9.16, R1.1, R2.1, R3.1, R4.1, R5.1, R13.1, U1.7 (VDD)
/i2c_scl: J9.12, U1.22 (SCL)
/i2c_sda: J9.10, U1.21 (SDA)
/lcd_bl: J9.1, R11.1
/lcd_clk: J6.9 (SCL), J9.9
/lcd_cs: J6.8 (CS), J9.7
/lcd_dc: J6.7 (D/C), J9.5
/lcd_mosi: J6.10 (SDA), J9.11
/lcd_rst: J6.11 (RST), J9.3
/ts1: J1#2.1, R6.1
/ts2: J2#2.1, R7.1
/ts3: J3.1, R8.1
/ts4: J4.1, R9.1
/ts5: J5.1, R10.1
/ts_irq: J9.8, U1.9 (CS15)
GND: C1.2, C1#2.2, C2.2, C3.2, C4.2, C5.2, J1.C5 (GND), J2.2, J6.1 (GND), J6.5 (GND), J6.6 (GND), J6.12 (GND), J9.13, J9.14, Q1.2 (E), R12.2, U1.8 (VSS), U1.10 (CS14), U1.11 (CS13), U1.17 (CS7), U1.18 (CS6), U1.19 (CS5), U1.25 (EP)
unnamed: BZ1.2 (+), D6.2 (A), R14.2
unnamed: D1.1 (A), R1.2
unnamed: D1.2 (K), U1.16 (CS8)
unnamed: D2.1 (A), R2.2
unnamed: D2.2 (K), U1.15 (CS9)
unnamed: D3.1 (A), R3.2
unnamed: D3.2 (K), U1.14 (CS10)
unnamed: D4.1 (A), R4.2
unnamed: D4.2 (K), U1.13 (CS11)
unnamed: D5.1 (A), R5.2
unnamed: D5.2 (K), U1.12 (CS12)
unnamed: J6.2 (LEDK), Q1.3 (C)
unnamed: Q1.1 (B), R11.2, R12.1
unnamed: C1#2.1, U1.5 (CMOD)
unnamed: R6.2, U1.1 (CS0)
unnamed: R7.2, U1.2 (CS1)
unnamed: R8.2, U1.3 (CS2)
unnamed: R9.2, U1.4 (CS3)
unnamed: R10.2, U1.20 (CS4)
unnamed: C2.1, U1.6 (VCC)
unnamed: R14.1, U1.23 (~HI)
unnamed: C3.1, R13.2, U1.24 (~XRES)

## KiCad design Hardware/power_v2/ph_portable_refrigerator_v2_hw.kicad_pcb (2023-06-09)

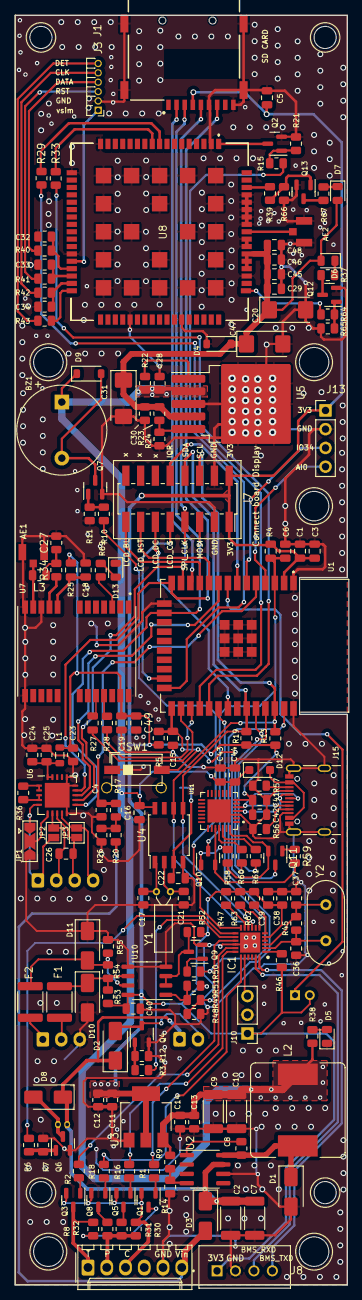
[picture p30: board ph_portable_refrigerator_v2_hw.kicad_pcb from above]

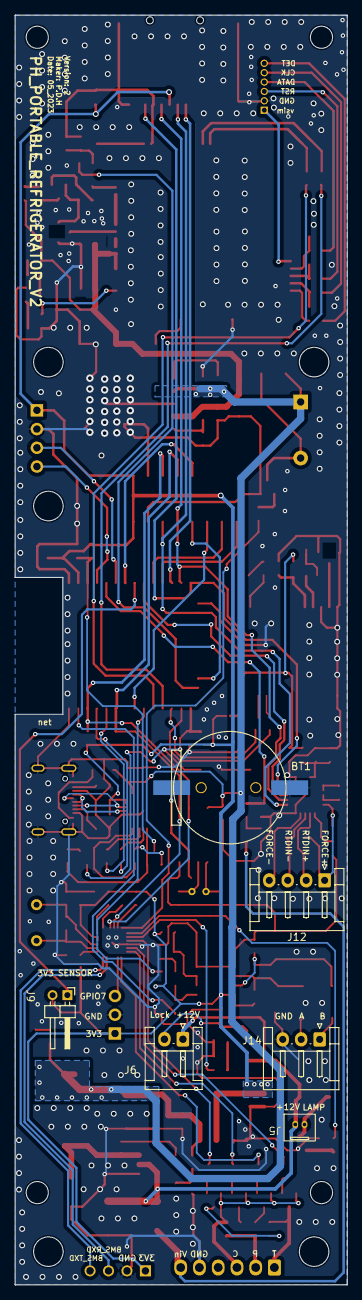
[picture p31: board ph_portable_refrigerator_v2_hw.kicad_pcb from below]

Board: 2 copper layers, 45.0 x 172.0 mm, 179 parts (6 on the bottom side), 131 nets.

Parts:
AE1: GPS; Antenna_RF
AE2: gsm; Antenna_RF
BT1: cr1220; BT_CR1220
BZ1: Buzzer-Device; Buzzer_12x9.5RM7.6
C1, C6, C15, C18, C22, C29, C41, C43: 10uF; C_0805_2012Metric
C2, C7, C9, C10: 10uF; R_2010_5025Metric
C3, C5, C16, C26, C40, C42, C44, C45, C49: 100nF; C_0805_2012Metric
C4, C12, C14, C25, C38: 100nF; R_0805_2012Metric
C8, C27: 10nF; R_0805_2012Metric
C11, C13, C28, C39: 10uF; R_0805_2012Metric
C17, C21: 7pF; R_0805_2012Metric
C19: 1uF; C_0805_2012Metric
C20, C31, C47: 100uF; CP_EIA-6032-15_Kemet-U
C23, C24, C30: 1uF; R_0805_2012Metric
C32, C33, C34: 22pF; R_0805_2012Metric
C36, C37: 18pF; R_0805_2012Metric
C46: 33pF; C_0805_2012Metric
C48: 10pF; C_0805_2012Metric
D1, D3: SS3x_SMA; D_SMA
D2: m7; D_SMA
D4: 5.1V; D_SOD-123
D5: RED; LED_0805_2012Metric
D6, D7, D13: blue; LED_0805_2012Metric
D8: M7; D_SMA
D9: 1N4148_T4; D_SOD-123
D10, D11: D_TVS; D_SMA
D12: 1N4007_T7; D_SOD-123F
F1, F2: Fuse; Fuse_SMD_1812
IC1: SC16IS750IBS,128; QFN50P400X400X100-25N
J1: microSD_Card
J3: Conn_01x06_Pin; PinHeader_1x06_P1.27mm_Horizontal
J5: lamp; Header_2P_1.25mm
J6: lock_latch; JST_EH_S2B-EH_1x02_P2.50mm_Horizontal
J7: Conn_02x08_Odd_Even; PinSocket_2x08_P2.00mm_Vertical_SMD
J8: Header_4P_2.54mm
J9: sensor; PinHeader_1x02_P2.00mm_Horizontal
J10: Extra; PinHeader_1x03_P2.54mm_Vertical
J11: refrigerator; Molex_KK-254_AE-6410-06A_1x06_P2.54mm_Vertical
J12: Conn_01x04; JST_EH_S4B-EH_1x04_P2.50mm_Horizontal
J13: Extra; PinHeader_1x04_P2.54mm_Vertical
J14: Conn_01x03_Pin; JST_EH_S3B-EH_1x03_P2.50mm_Horizontal
J15: USB_C_Receptacle_USB2.0; USB_C_Receptacle_GCT_USB4105-xx-A_16P_TopMnt_Horizontal
JP1: SolderJumper_3_Bridged12; SolderJumper-3_P2.0mm_Open_TrianglePad1.0x1.5mm
JP2, JP3: SolderJumper_2_Open; SolderJumper-2_P1.3mm_Open_Pad1.0x1.5mm
L1: L600R; L_0805_2012Metric
L2: 15uH; L_Bourns_SRR1260
L3: 22uH; R_0805_2012Metric
Q1, Q3, Q5, Q8, Q10, Q11: C1815; SOT-23
Q2, Q7, Q12, Q13: C1815_SOT23; SOT-23
Q4: AO3400A; SOT-23-3
Q6: AO3400A; SOT-23
Q9: 2SC1815-HF; SOT-23
R1, R2, R10, R15, R16, R17, R18, R26, R38, R45, R46, R47: 1k; R_0805_2012Metric
R3, R6: 100R; R_0805_2012Metric
R4: 10K; C_0805_2012Metric
R5, R7, R11, R12, R20, R21, R22, R58, R59: 10k; R_0805_2012Metric
R8: 680R; R_0805_2012Metric
R9: 10k1%; R_0805_2012Metric
R13, R19, R39, R49, R53, R55, R62, R63, R64: 4.7K; R_0805_2012Metric
R14: 4k7 1%; R_0805_2012Metric
R23: 240R/1%; R_0805_2012Metric
R24: 120R/1%; R_0805_2012Metric
R25: 10k; C_0805_2012Metric
R27: 22R; C_0805_2012Metric
R28, R29, R33, R40, R41, R42, R43: 22R; R_0805_2012Metric
R30: 47k; R_0805_2012Metric
R31: 4.7k; R_0805_2012Metric
R32: 810R; R_0805_2012Metric
R34: 10R; R_0805_2012Metric
R36: 400R; R_0805_2012Metric
R37, R67, R69: 1K; R_0805_2012Metric
R48, R51, R52: 10K; R_0805_2012Metric
R50: 2.2K; R_0805_2012Metric
R54: 120R; R_0805_2012Metric
R56, R57: 5.1K; R_0805_2012Metric
R60, R61: 470R; R_0805_2012Metric
R65, R66: 47K; R_0805_2012Metric
SW1: button_2pin; SW_DIP_SPSTx01_Slide_6.7x4.1mm_W6.73mm_P2.54mm_LowProfile_J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
U1: ESP32-WROOM; MODULE_ESP32-WROOM-32
U2: TPS5430DDAR; SOIC-8-1EP_3.9x4.9mm_P1.27mm_EP2.29x3mm_ThermalVias
U3: AMS1117-3.3; SOT-223-3_TabPin2
U4: DS1307Z+_SMD; SOIC-8W_5.3x5.3mm_P1.27mm
U5: MIC29302WU; TO-263-5_TabPin3
U6: MAX31865_TQFN; QFN-20-1EP_5x5mm_P0.65mm_EP3.35x3.35mm
U7: NEO-M8M; XCVR_NEO-M9N-00B
U8: SIM_COM_A7670; SimCom_A7670
U10: MAX485; SO-8_3.9x4.9mm_P1.27mm
U11: CP2102-GM; CP2102
Y1: 32.768; Crystal_DS26_D2.0mm_L6.0mm_Horizontal
Y2: 14.7456 MHz; Crystal_HC49-4H_Vertical

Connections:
+3V3: C1.1, C3.1, C5.1, C11.1, C12.1, C19.1, C23.1, C38.2, C39.2, C40.2, C41.1, C42.1, C49.1, IC1.4 (VDD), IC1.5 (I2C/SPI), J1.P4 (VDD), J7.1, J7.2, J8.1, J9.2, J10.1, J13.1, L1.1, R4.2, R5.1, R13.1, R19.1, R25.1, R46.2, R47.1, R51.1, R52.1, R53.1, R62.2, R63.2, U1.2 (3V3), U3.2 (VO), U7.23 (VCC), U10.8 (VCC), U11.6 (VDD), U11.7 (REGIN)
+3V8: C20.1, C29.1, C30.1, C31.1, C45.1, C46.1, C47.1, C48.1, D4.1 (K), D6.1 (A), D7.1 (A), R23.1, U5.4 (VOUT), U8.55 (VBAT_1), U8.56 (VBAT_2), U8.57 (VBAT_3)
+5V: BZ1.1 (-), C9.1, C10.1, C13.1, C14.1, C16.1, C28.1, C43.1, C44.1, D9.1 (K), D12.1 (K), L2.2, R9.1, R22.1, R38.2, U3.3 (VI), U4.8 (VCC), U5.2 (VIN), U11.8 (VBUS)
+12V: C2.1, C7.1, D2.1 (K), D3.1 (K), D8.1 (K), J5.1, J6.1, U2.7 (VIN)
+BATT: BT1.1, C22.1, U4.3 (VBAT)
/AI01: C4.1, R17.1, U1.5 (SENSOR_VN)
/ESP_RX: R61.1, U1.34 (RXD0)
/ESP_TX: R60.1, U1.35 (TXD0)
/GPS/Timepluse: R69.1, U7.3 (TIMEPULSE)
/GPS/gps_ant: AE1.1 (A), L3.2, U7.11 (RF_IN)
/GPS/vRF: R34.1, U7.9 (VCC_RF)
/GPS_RXD: R28.1, U1.27 (IO16)
/GPS_TXD: R27.1, U1.26 (IO4)
/GSM Block/NetLight: R64.1, U8.52 (NETLIGHT)
/GSM Block/Status: R39.1, U8.66 (STATUS)
/GSM Block/VSIM: J3.1, U8.30 (SIM_VDD)
/GSM Block/pwrkey: Q2.3 (C), U8.1 (PWRKEY)
/GSM Block/sim_clk: C33.1, R41.1, U8.32 (SIM_CLK)
/GSM Block/sim_clk#: J3.3, R41.2
/GSM Block/sim_data: C32.1, R40.1, U8.31 (SIM_DATA)
/GSM Block/sim_data#: J3.4, R40.2
/GSM Block/sim_det: R43.1, U8.34 (SIM_DET)
/GSM Block/sim_det#: J3.6, R43.2
/GSM Block/sim_rst: C34.1, R42.1, U8.33 (SIM_RST)
/GSM Block/sim_rst#: J3.5, R42.2
/GSM_PWR_KEY: R15.1, U1.24 (IO2)
/GSM_RXD: R33.1, U1.29 (IO5)
/GSM_TXD: R29.1, U1.28 (IO17)
/I2C Expand Block/BMS_RXD: IC1.23 (TX), J8.3
/I2C Expand Block/BMS_TXD: IC1.24 (RX), J8.4
/I2C Expand Block/Buzzer: IC1.12 (GPIO0), R10.1
/I2C Expand Block/C: J11.3, Q1.2 (E), Q3.2 (E), Q5.2 (E), Q8.2 (E), R30.1
/I2C Expand Block/Lamp: IC1.13 (GPIO1), R6.1
/I2C Expand Block/Lock: IC1.14 (GPIO2), R3.1
/I2C Expand Block/P: J11.2, R30.2, R31.2, R32.2
/I2C Expand Block/P1: IC1.15 (GPIO3), R1.1
/I2C Expand Block/P2: IC1.17 (GPIO4/~DSR), R2.1
/I2C Expand Block/P3: IC1.18 (GPIO5/~DTR), R16.1
/I2C Expand Block/P4: IC1.19 (GPIO6/~CD), R18.1
/I2C Expand Block/T: J11.1, Q3.3 (C), R8.2
/I2C Expand Block/Vin: D3.2 (A), J11.6, R20.2
/I2C Expand Block/a0/cs: IC1.6 (A0/CS), R62.1
/I2C Expand Block/a1/si: IC1.7 (A1/SI), R63.1
/I2C Expand Block/gpio7/ri: IC1.20 (GPIO7/RI), J10.3
/I2C_SCL: IC1.9 (SCL), J7.6, R13.2, U1.36 (IO22), U4.6 (SCL)
/I2C_SDA: IC1.10 (SDA/VSS), J7.8, R19.2, U1.33 (IO21), U4.5 (SDA)
/LCD_BL: J7.15, U1.11 (IO26)
/LCD_CS: J7.9, U1.23 (IO15)
/LCD_DC: J7.11, U1.31 (IO19)
/LCD_RST: J7.13, U1.10 (IO25)
/MCU Block/AI00: J13.4, U1.4 (SENSOR_VP)
/MCU Block/CP_DTR: Q11.2 (E), R58.2, U11.28 (~DTR)
/MCU Block/CP_RST: Q10.2 (E), R59.2, U11.24 (~RST)
/MCU Block/CP_RXD: R60.2, U11.25 (RXD)
/MCU Block/CP_TXD: R61.2, U11.26 (TXD)
/MCU Block/IO34: J13.3, U1.6 (IO34)
/MCU Block/USB_D+: J15.A6 (D+), J15.B6 (D+), U11.4 (D+)
/MCU Block/USB_D-: J15.A7 (D-), J15.B7 (D-), U11.5 (D–)
/SENSOR_DOOR: J9.1, U1.8 (IO32)
/SOFTWARE_RXD: R48.2, R49.1, U1.37 (IO23)
/SOFTWARE_TXD: R50.1, U1.30 (IO18)
/SPI_CLK: J1.P5 (CLK), J7.7, U1.13 (IO14), U6.12 (SCLK)
/SPI_MAX_CS: U1.9 (IO33), U6.13 (~CS)
/SPI_MISO: J1.P7 (DAT0), U1.14 (IO12), U6.14 (SDO)
/SPI_MOSI: J1.P3 (CMD), J7.5, U1.16 (IO13), U6.11 (SDI)
/SPI_SD_CS: J1.P2 (CD/DAT3), U1.12 (IO27)
/TS_IQR: J7.10, U1.7 (IO35)
/Uart to RS485/A: F1.2, J14.2
/Uart to RS485/B: F2.2, J14.1
ESP_EN: C6.1, Q10.3 (C), R4.1, U1.3 (EN)
ESP_IO0: C15.1, Q11.3 (C), R5.2, SW1.2, U1.25 (IO0)
GND: AE1.2 (Shield), AE1.3 (Shield), AE2.2 (Shield), AE2.3 (Shield), BT1.2, C1.2, C2.2, C3.2, C4.2, C5.2, C6.2, C7.2, C9.2, C10.2, C11.2, C12.2, C13.2, C14.2, C15.2, C16.2, C17.1, C18.2, C19.2, C20.2, C21.1, C22.2, C23.2, C24.2, C25.2, C27.2, C28.2, C29.2, C30.2, C31.2, C32.2, C33.2, C34.2, C36.1, C37.1, C38.1, C39.1, C40.1, C41.2, C42.2, C43.2, C44.2, C45.2, C46.2, C47.2, C48.2, C49.2, D1.2 (A), D4.2 (A), D5.2 (K), D10.2 (A2), D11.1 (A1), D13.2 (K), IC1.16 (VSS), IC1.25 (GND), J1.P6 (VSS), J1.P9 (CD), J1.SH1 (SHIELD), J1.SH2 (SHIELD), J1.SH3 (SHIELD), J1.SH4 (SHIELD), J3.2, J7.3, J7.4, J8.2, J10.2, J11.5, J13.2, J14.3, J15.A1 (GND), J15.A8 (SBU1), J15.A12 (GND), J15.B1 (GND), J15.B8 (SBU2), J15.B12 (GND), J15.S1 (SHIELD), JP1.3 (B), Q2.2 (E), Q4.2 (S), Q6.2 (S), Q7.2 (E), Q9.2 (E), Q12.2 (E), Q13.2 (E), R7.1, R11.1, R12.1, R14.2, R21.2, R24.2, R26.1, R48.1, R55.2, R56.1, R57.1, R65.1, R66.1, SW1.1, U1.1 (GND), U1.15 (GND), U1.38 (GND), U1.39_1, U1.39_2, U1.39_3, U1.39_4, U1.39_5, U1.39_6, U1.39_7, U1.39_8, U1.39_9, U2.6 (GND), U3.1 (GND), U4.4 (GND), U5.3 (GND), U6.10 (GND2), U6.15 (DGND), U6.16 (GND1), U6.21 (PAD), U7.10 (GND), U7.12 (GND), U7.13 (GND), U7.24 (GND), U8.2 (GND_1), U8.17 (GND_2), U8.18 (GND_3), U8.29 (GND_4), U8.39 (GND_5), U8.45 (GND_6), U8.46 (GND_7), U8.54 (GND_8), U8.58 (GND_9), U8.59 (GND_10), U8.61 (GND_11), U8.62 (GND_12), U8.63 (GND_13), U8.64 (GND_14), U8.65 (GND_15), U8.69 (GND_16), U8.70 (GND_17), U8.71 (GND_18), U8.72 (GND_19), U8.73 (GND_20), U8.74 (GND_21), U8.75 (GND_22), U8.76 (GND_23), U8.77 (GND_24), U8.78 (GND_25), U8.79 (GND_26), U8.80 (GND_27), U8.81 (GND_28), U8.82 (GND_29), U8.83 (GND_30), U8.84 (GND_31), U8.85 (GND_32), U8.86 (GND_33), U8.87 (GND_34), U8.88 (GND_35), U10.4 (DI), U10.5 (GND), U11.3 (GND), U11.29 (GND)
unnamed: AE2.1 (A), U8.60 (RF_ANT)
unnamed: BZ1.2 (+), D9.2 (A), Q7.3 (C)
unnamed: C27.1, L3.1, R34.2
unnamed: C8.2, D1.1 (K), L2.1, U2.8 (PH)
unnamed: D2.2 (A), J6.2, Q4.3 (D)
unnamed: D5.1 (A), R38.1
unnamed: D6.2 (K), R37.2
unnamed: D7.2 (K), R67.2
unnamed: D8.2 (A), J5.2, Q6.3 (D)
unnamed: D10.1 (A1), F1.1, R53.2, R54.1, U10.6 (A)
unnamed: D11.2 (A2), F2.1, R54.2, R55.1, U10.7 (B)
unnamed: D12.2 (A), J15.A4 (VBUS), J15.A9 (VBUS), J15.B4 (VBUS), J15.B9 (VBUS)
unnamed: D13.1 (A), R69.2
unnamed: C36.2, IC1.2 (XTAL1), R45.2, Y2.2
unnamed: C37.2, IC1.3 (XTAL2), R45.1, Y2.1
unnamed: IC1.11 (~IRQ), R47.2
unnamed: IC1.1 (~RESET), R46.1
unnamed: J12.1, JP1.1 (A), JP2.2 (B), U6.5 (FORCE+)
unnamed: C26.1, J12.2, JP2.1 (A), U6.7 (RTDIN+)
unnamed: C26.2, J12.3, JP3.2 (B), U6.8 (RTDIN-)
unnamed: J12.4, JP3.1 (A), U6.9 (FORCE-)
unnamed: J15.A5 (CC1), R56.2
unnamed: J15.B5 (CC2), R57.2
unnamed: JP1.2 (C), U6.6 (FORCE2)
unnamed: Q1.1 (B), R1.2
unnamed: Q1.3 (C), R8.1
unnamed: Q2.1 (B), R15.2, R21.1
unnamed: Q3.1 (B), R2.2
unnamed: Q4.1 (G), R3.2, R12.2
unnamed: Q5.1 (B), R16.2
unnamed: Q5.3 (C), R31.1
unnamed: Q6.1 (G), R6.2, R7.2
unnamed: Q7.1 (B), R10.2, R11.2
unnamed: Q8.1 (B), R18.2
unnamed: Q8.3 (C), R32.1
unnamed: Q9.1 (B), R50.2
unnamed: Q9.3 (C), R52.2, U10.2 (~RE), U10.3 (DE)
unnamed: Q10.1 (B), R58.1
unnamed: Q11.1 (B), R59.1
unnamed: Q12.1 (B), R64.2, R65.2
unnamed: Q12.3 (C), R37.1
unnamed: Q13.1 (B), R39.2, R66.2
unnamed: Q13.3 (C), R67.1
unnamed: R17.2, R20.1, R26.2
unnamed: C8.1, U2.1 (BOOT)
unnamed: R9.2, R14.1, U2.4 (VSENSE)
unnamed: C17.2, U4.1 (X1), Y1.1
unnamed: C21.2, U4.2 (X2), Y1.2
unnamed: R23.2, R24.1, U5.5 (ADJ)
unnamed: R22.2, U5.1 (EN)
unnamed: R36.1, U6.1 (BIAS), U6.2 (REFIN+)
unnamed: C24.1, C25.1, L1.2, U6.19 (DVDD), U6.20 (VDD)
unnamed: R36.2, U6.3 (REFIN-), U6.4 (ISENSOR)
unnamed: R28.2, U7.21 (RXD/SPI_MOSI)
unnamed: R27.2, U7.20 (TXD/SPI_MISO)
unnamed: C18.1, R25.2, U7.8 (~RESET)
unnamed: R33.2, U8.10 (RXD)
unnamed: R29.2, U8.9 (TXD)
unnamed: R49.2, R51.2, U10.1 (RO)

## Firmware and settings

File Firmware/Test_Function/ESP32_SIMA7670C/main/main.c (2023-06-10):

// #include "app_main.h"

#include <stdio.h>
#include <stdint.h>
#include <string.h>

/* library RTOS */
#include "freertos/FreeRTOS.h"
#include "freertos/task.h"
#include "freertos/semphr.h"
#include "freertos/event_groups.h"

/* library ESP */
#include "esp_system.h"
#include "esp_log.h"
#include "driver/uart.h"
#include "driver/gpio.h"

/* config module sim GSM */
#define GSM_PWR_KEY (GPIO_NUM_2)
#define GSM_TXD (GPIO_NUM_5)
#define GSM_RXD (GPIO_NUM_17)
#define GSM_UART_PORT (UART_NUM_1)
#define GSM_BAUD_RATE (115200)
#define GSM_WAKEUP_PIN 2

/* task Handle RTOS */
TaskHandle_t Task_1 = NULL;
TaskHandle_t Task_2 = NULL;

/* static variable */
static const char *TAG = "SIM_A7670";
const int GSM_RX_BUF_SIZE = 1024;

/* void function task */
void GSM_Init();
int GSM_Write_CMD(const char *logName, const char *data);
void GSM_Read_Data(const char *logName,  uint8_t *data);
void Task_GSM_Write(void *arg);
void Task_GSM_Read(void *arg);


void app_main(void)
{
    /* init module sim A7670 communication with UART */
    GSM_Init();
    vTaskDelay(10000/portTICK_PERIOD_MS);

    /* create task rtos */
    xTaskCreate(&Task_GSM_Read, "GSM_Read_Data", 1024*2, NULL, 1, Task_2);
    xTaskCreate(&Task_GSM_Write, "GSM_Write_AT", 1024*2, NULL, 1, Task_1);
}

void Task_GSM_Write(void *arg)
{
    char GSM_AT[] = "AT\n";
    char GSM_CPIN[] = "AT+CPIN?+\n";
    while(1)
    {
        printf("%s", GSM_AT);
        uart_write_bytes(GSM_UART_PORT, &GSM_AT, strlen(GSM_AT));
        vTaskDelay(2000/portTICK_PERIOD_MS);
    }
}

void Task_GSM_Read(void *arg)
{
    static const char *GSM_Read_TAG  = "GSM_READ";
    esp_log_level_set(GSM_Read_TAG, ESP_LOG_INFO);
    uint8_t * data = (uint8_t*)malloc(GSM_RX_BUF_SIZE);
    while(1)
    {
        GSM_Read_Data(GSM_Read_TAG, data);
    }
    free(data);
}

void GSM_Init()
{
    /* config UART */
    const uart_config_t uart_config = {
        .baud_rate = GSM_BAUD_RATE,
        .data_bits = UART_DATA_8_BITS,
        .parity = UART_PARITY_DISABLE,
        .stop_bits = UART_HW_FLOWCTRL_DISABLE,
        .source_clk = UART_SCLK_DEFAULT,
    };

    uart_driver_install(GSM_UART_PORT, GSM_RX_BUF_SIZE * 2, 0, 0, NULL, 0);
    uart_param_config(GSM_UART_PORT, &uart_config);
    uart_set_pin(GSM_UART_PORT, GSM_TXD, GSM_RXD, UART_PIN_NO_CHANGE, UART_PIN_NO_CHANGE);
    ESP_LOGI(TAG, "Init GSM finish");

    /* config GPIO WAKEUP */
    gpio_set_direction(GSM_WAKEUP_PIN, GPIO_MODE_OUTPUT);

    vTaskDelay(3000/portTICK_PERIOD_MS);

    gpio_set_level(GSM_WAKEUP_PIN, 1);
    vTaskDelay(5000/portTICK_PERIOD_MS);
    gpio_set_level(GSM_WAKEUP_PIN, 0);
    ESP_LOGI(TAG, "Turn on GSM");
}

int GSM_Write_CMD(const char *logName, const char *data)
{
    const int len = strlen(data);
    const int txBytes = uart_write_bytes(GSM_UART_PORT, data, len);
    ESP_LOGI(logName, "Wrote %d bytes", txBytes);
    return txBytes;
}

void GSM_Read_Data(const char *logName, uint8_t *data)
{
    const int rxBytes = uart_read_bytes(GSM_UART_PORT, data, GSM_RX_BUF_SIZE, 100 / portTICK_PERIOD_MS);
    if(rxBytes > 0)
    {
        data[rxBytes] = '\0';
        ESP_LOGI(logName, "Read %d bytes: %s", rxBytes, data);
    }
}

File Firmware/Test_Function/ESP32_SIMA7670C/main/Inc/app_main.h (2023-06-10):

#ifndef _APP_MAIN_H_
#define _APP_MAIN_H_

/* library system */

#include <stdio.h>
#include <stdint.h>
#include <string.h>

/* config module sim GSM */
#define GSM_PWR_KEY (GPIO_NUM_2)
#define GSM_TXD (GPIO_NUM_5)
#define GSM_RXD (GPIO_NUM_17)
#define GSM_UART_PORT (UART_NUM1)
#define GSM_BAUD_RATE (115200)

/* void function task */
void GSM_Init();
void GSM_Write_CMD(const char *logName, const char *data);
void GSM_Read_Data(const char *logName);

#endif

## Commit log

2023-05-18 layout PCB MCU, layout PCB display, edit nanosim
    [GSM_Block.kicad_sch, HEADER_Connect_Block.kicad_sch, I2C_Expand_Block.kicad_sch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]
2023-05-19 Add Ho so dac ta tu lanh di dong
2023-05-22 Oder PCB, Viet tai lieu mo ta hardware
    [ph_portable_refrigerator_display_hw_v2-B_Cu.gbl, ph_portable_refrigerator_display_hw_v2-B_Mask.gbs, ph_portable_refrigerator_display_hw_v2-B_Paste.gbp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]
2023-06-08 Han Board MCU va board Display
    [GSM_Block.kicad_sch, MCU_Block.kicad_sch, ph_portable_refrigerator_display_hw_v2.kicad_sch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]
2023-06-09 Modify tx/rx UART0, LED GPS, pin rst/clk sim card
    [GSM_Block.kicad_sch, MCU_Block.kicad_sch, ph_portable_refrigerator_v2_hw.kicad_pcb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]
2023-06-09 create folder Hardware
    [GSM_Block.kicad_sch, HEADER_Connect_Block.kicad_sch, I2C_Expand_Block.kicad_sch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]
2023-06-10 Test function esp32-s7670c
